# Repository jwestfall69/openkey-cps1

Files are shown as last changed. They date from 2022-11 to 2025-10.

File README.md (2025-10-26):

# openkey-cps1
---
* [Overview](#overview)
* [Project Status](#project-status)
* [Supported C Boards](#supported-c-boards)
* [CPS 1 Case](#cps-1-case)
* [Supported Games / B-XX Chips](#supported-games--b-xx-chips)
  * [CPS 1](#cps-1)
  * [CPS 1.5](#cps-15)
  * [B-XX](#b-xx)
* [Hardware](#hardware)
  * [PCB Manufacturing](#pcb-manufacturing)
  * [BOM](#bom)
  * [Assembly](#assembly)
    * [CPS 1](#cps-1-1)
    * [CPS 1.5](#cps-15-1)
* [Programming](#programming)
  * [Hardware](#hardware-1)
  * [Software](#software)
* [Installation](#installation)
  * [CPS 1](#cps-1-2)
  * [CPS 1.5](#cps-15-2)
  * [Reset Header (optional)](#reset-header-optional)
    * [Reset Capacitor Locations](#reset-capacitor-locations)
    * [Reset Signal Locations](#reset-signal-locations)
    * [Reset Cable](#reset-cable)
    * [Reset Delay Jumper](#reset-delay-jumper)
* [Reverting a modified C Board](#reverting-a-modified-c-board)

## Overview
This is an open source/hardware implementation of an on the fly CPS B-21 chip programmer that consists of a PCB that sits between CPS1/1.5 B and C boards.

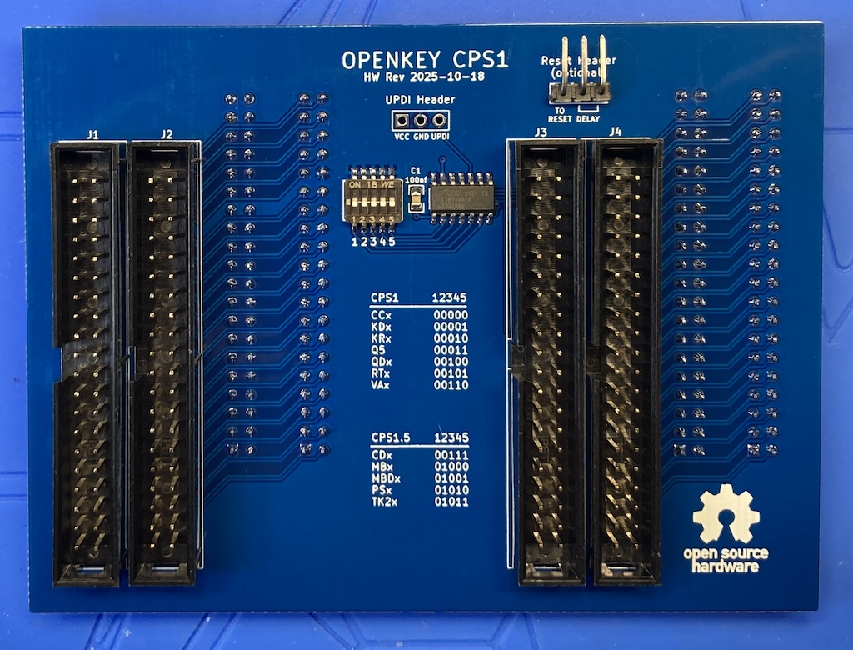
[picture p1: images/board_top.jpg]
board pics
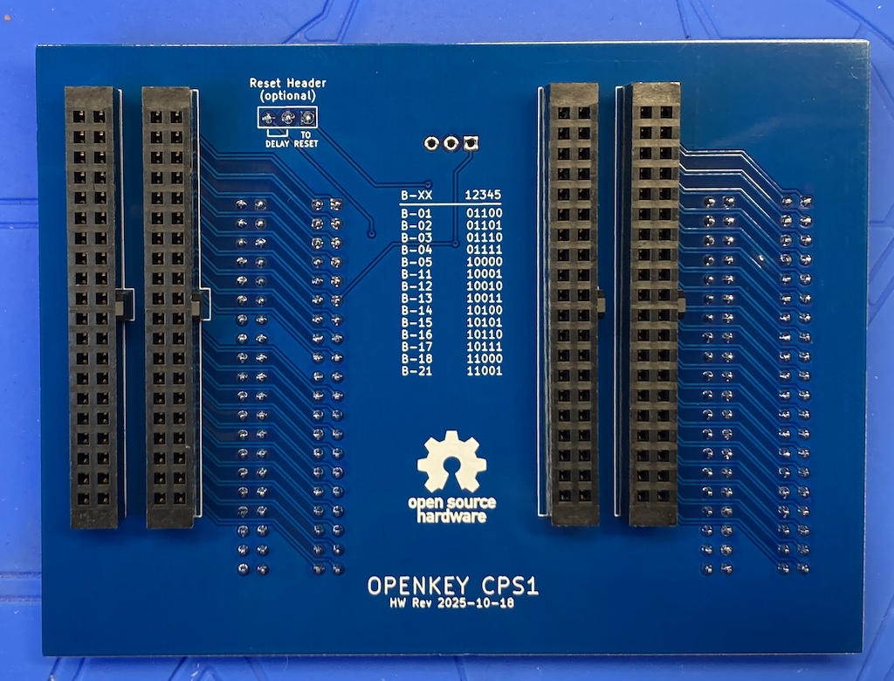
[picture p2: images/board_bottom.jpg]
board pics
 

Installed:<br>
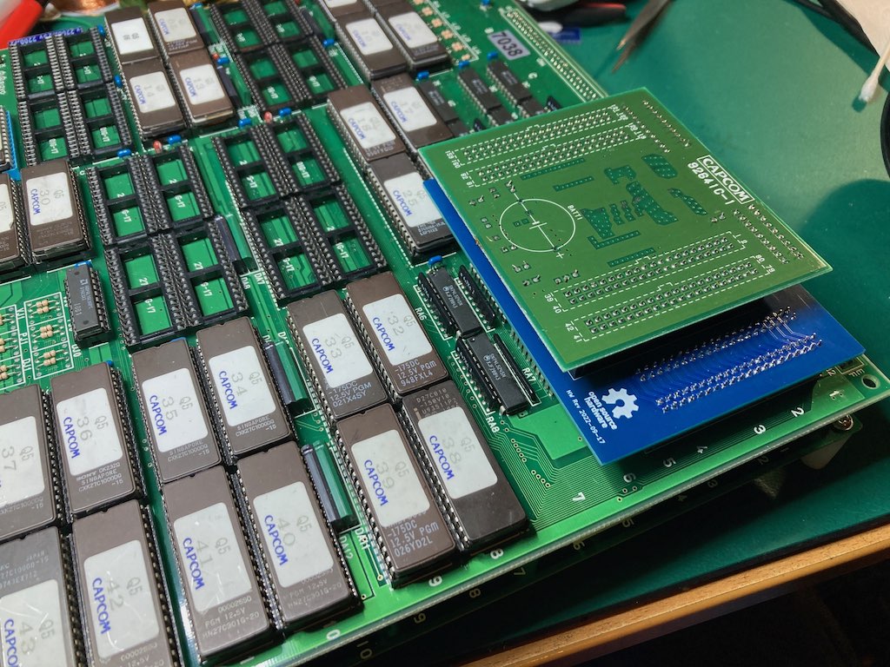
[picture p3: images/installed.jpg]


This project is providing the same functionality as [Undamned's InfiniKey-CPS1](https://www.arcade-projects.com/threads/infinikey-cps1.8337/).  The lack of supply is what prompted me to make openkey-cps1.  If they ever end up coming back in stock please consider purchasing those to support [Undamned](https://www.arcade-projects.com/forums/temple-of-the-undamned.77/)'s work.

Details on *how* to program the CPS B-21 chip configuration can be found in [Eduardo Cruz](http://arcadehacker.blogspot.com/)'s [write up](http://arcadehacker.blogspot.com/2015/04/capcom-cps1-part-1.html) and [youtube video](https://www.youtube.com/watch?v=IBZc__9sM28).  Additional information is also comes from [cps2-reverse](https://gitlab.com/loic.petit/cps2-reverse) project which has details on the [CPS B-21](https://gitlab.com/loic.petit/cps2-reverse/-/tree/master/DLs/DL-0921) chip.

Details on *what* to program can be found in MAME's code for the [CPS1](https://github.com/mamedev/mame/blob/master/src/mame/capcom/cps1_v.cpp#L470).

## Project Status
**PCB:** Done

**Firmware:** Need to get untested games tested

**Documentation:** Done

## Supported C Boards
The following unmodified C Boards are supported

* [90630C-4](https://www.mvs-scans.com/index.php/CPS1_-_C_Board_90630C-4)
* [90631C-5](https://www.mvs-scans.com/index.php/CPS1_-_C_Board_90631C-5)
* [92641C-1](https://www.mvs-scans.com/index.php/CPS1_-_C_Board_92641C-1)

## CPS 1 Case
openkey-cps1 will not fit in the CPS 1 case.  As far as I know only Varith and Capcom World 2 came in a case.  You can still use openkey-cps1 to desuicide the C board.  Replace the battery then boot up the game with openkey-cps1 installed.  Verify it runs as expected, then power off, remove openkey-cps1 and reinstall the board in the case.

## Supported Games / B-XX Chips
openkey-cps1 supports either having a 5 position switch or using solder jumpers for picking what to program into the B-21 Chip.  For the switch, ensure the switches are fully set.  You should hear a click sound as you change the position.

 Below is a list of supported configurations/games and what switches/jumpers must be used for each.

### CPS 1
| Switch<br>12345 | Program ROM Labels | Game Name | Tested / Working |
|:---:|:---:|---|:---:|
| 00000 | CCE<br>CCJ<br>CCU<br> | Captain Commando | YES |
| 00001 | KDE<br>KDJ<br>KDU | The King of Dragons | |
| 00010 | KR_23E<br>KR_23J<br>KR_23U | Knights of the Round | YES |
| 00011 | Q5 | Capcom World 2 | YES |
| 00100 | QDU | Quiz & Dragons | YES |
| 00101 | RTE<br>RTJ<br>RTU | Three Wonders | YES |
| 00110 | VAE<br>VAJ<br>VAU | Varth | YES |

### CPS 1.5
| Switch<br>12345 | Program ROM Labels | Game Name | Tested / Working |
|:---:|:---:|---|:---:|
| 00111 | CDE<br>CDJ<br>CDT<br>CDU | Cadillacs & Dinosaurs | YES |
| 01000 | MBE<br>MBJ<br>MBU | Slam Masters / Muscle Bomber | YES |
| 01001 | MBDE<br>MBDJ | Muscle Bomber Duo | |
| 01010 | PSE<br>PSH<br>PSJ<br>PSU | Punisher | YES |
| 01011 | TK2E<br>TK2J<br>TK2U | Warriors of Fate | |

### B-XX
For B-XX chips prior to B-21 the configurations were hard coded into the chip.  Its possible to program the B-21 to mimic these older chips.

Some older B-XX boards will have the number stamped on instead of etched into the chip.  These stamped numbers maybe incorrect.  For example I have a final fight board that has 04 stamped on as the XX number.  Picking B-04 on openkey-cps1 didn't work.  After dumping the program roms I was able to determine it was the ffightua romset.   [Mame](https://github.com/mamedev/mame/blob/master/src/mame/capcom/cps1_v.cpp#L1754) shows this romset actually uses B-01.  Switching to B-01 made the game work.

| Switch<br>12345 |  B-XX  | Tested / Working |
|:---:|:---:|:---:|
| 01100 | B-01 | YES |
| 01101 | B-02 | |
| 01110 | B-03 | |
| 01111 | B-04 | YES |
| 10000 | B-05 | |
| 10001 | B-11 | YES |
| 10010 | B-12 | YES |
| 10011 | B-13 | YES |
| 10100 | B-14 | YES |
| 10101 | B-15 | |
| 10110 | B-16 | YES |
| 10111 | B-17 | YES |
| 11000 | B-18 | |
| 11001 | B-21 | YES |

## Hardware
### PCB Manufacturing
There are no special requirements for manufacturing.

I've been using [jlcpcb](https://jlcpcb.com/) for PCB manufacturing.  Just watch out that by default they will add an order number to the silk screen unless you tell them not to.

### BOM
| Quantity | Description | Part Number | DigiKey | Mouser | Notes |
|:---:|---|---|---|---|---|
| 1 | ATtiny404 20Mhz | ATTINY404-SSN | [ATTINY404-SSN-ND](https://www.digikey.com/en/products/detail/microchip-technology/ATTINY404-SSN/9947546) | [556-ATTINY404-SSNR](https://www.mouser.com/ProductDetail/Microchip-Technology-Atmel/ATTINY404-SSNR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) | Other ATtiny tinyAVR 0/1/2-series models should be viable as well.  The code compiles to just under 1.5K in size, so any that have 2k or more of flash should work.  Just note I have only tested with 404s |
| 1 | 100nf / 0.1uf SMD Ceramic Capacitor 0805 Size | | | | |
| 1 | 5 Position Slide Switch | Würth Elektronik 416131160805 | [732-3855-2-ND](https://www.digikey.com/en/products/detail/w%C3%BCrth-elektronik/416131160805/3174531) | [710-416131160805](https://www.mouser.com/ProductDetail/Wurth-Elektronik/416131160805?qs=2kOmHSv6VfT1rqUsojuQog%3D%3D) | **Optional** not needed if using the solder jumpers to pick the game.
| 4 | CPS1: 2x20 Pin Male IDC connector<br>CPS1.5: 2x20pin Male Header (no shroud) | SBH11-PBPC-D20-ST-BK<br>N/A | [S9175-ND](https://www.digikey.com/en/products/detail/sullins-connector-solutions/SBH11-PBPC-D20-ST-BK/1990068)<br>[2x20 Pin Header](https://www.amazon.com/dp/B083DYVWDN?psc=1&ref=ppx_yo2ov_dt_b_product_details) | ?? | This is just a standard IDE male connector<br>This is just a normal 2x20 Pin header you might find for a PI's GPIO pins |
| 4 | 2x20 Pin Female socket | SFH11-PBPC-D20-ST-BK | [S9200-ND](https://www.digikey.com/en/products/detail/sullins-connector-solutions/SFH11-PBPC-D20-ST-BK/1990093) | ?? |  |

**IMPORTANT** For the 2x20 Pin Female socket, if you choose a different part, make sure you get ones that have the extra plastic on the edge as seen below.

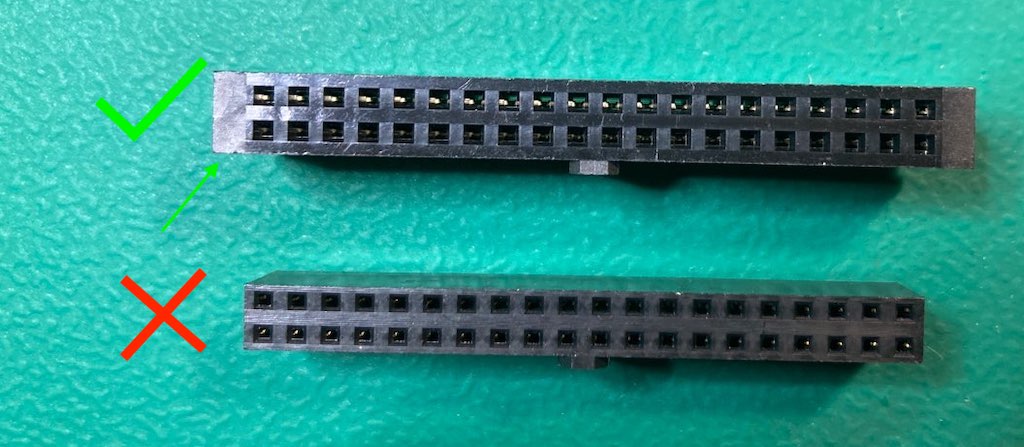
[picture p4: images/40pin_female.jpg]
40 pin female


The extra plastic prevents the connector from being inserted off-by-one.  An off-by-one insertion will cause a direct short to ground. This can cause catastrophic damage to your Game PCB if your power supply doesn't have short circuit protection.

Don't be fooled into thinking you don't need the extra plastic because you see the key. The bottom connector for example is too skinny for the key to actually prevent off-by-one insertion.  Ask me how I know ;)

### Assembly
#### CPS 1
Nothing special is needed when assembling a openkey-cps1 that will be used in a normal non-case'd CPS1 board.  Install SMD components first, then install the 40 pin male/female connectors.

#### CPS 1.5
Installing openkey-cps1 in a CPS 1.5 case is a tight fit height wise.  The pins that stick out of the C board are at the point of touching the top of the case.  If you are ok with this just use the 40 pin IDE style connectors.  Otherwise you can do the following.

To deal with this the best course of action is to only have raw pins for the male 40 pin connectors instead of ones with the plastic shroud.  This will allow the C board to sit flush with the openkey-cps1 board and reduce the height enough to not touch the top of the case.  Below is what has worked well for me, but there maybe better ways.

Some things to consider:
  * The normal pin length of a male pin is 6mm
  * The max pin height above the openkey-cps1 board should **not exceed 7mm**.  Any longer and the pin will bottom out on the female connector on the C Board.  This will cause the C board to not sit flush to the openkey-cps1 board and defeat the purpose of using raw pins.
  * You can't just install the normal 40pin IDE style connector then remove the shroud.  The resulting pin length ends up being 8mm.
  * You can't just install a normal 40 pin header and remove the plastic.  The resulting pin length ends up being 8mm.
  * The total length of metal pin on most headers is going to be 11.5mm
  * PCB thickness should be 1.6mm, which leave about 10mm worth of metal pin length we must deal with.

This method targets having 7mm above and 3mm below the openkey-cps1 board.  I've tried 6mm/4mm, but that 4mm is long enough there is risk it could hit/damage components on the B board.

You will want 4 normal 2x20 pin headers where the total metal length is 11.5mm.  Additionally you will want something you can use as a 1.5mm spacer.  I'm using the 2 black 24AWG wires in the picture below.

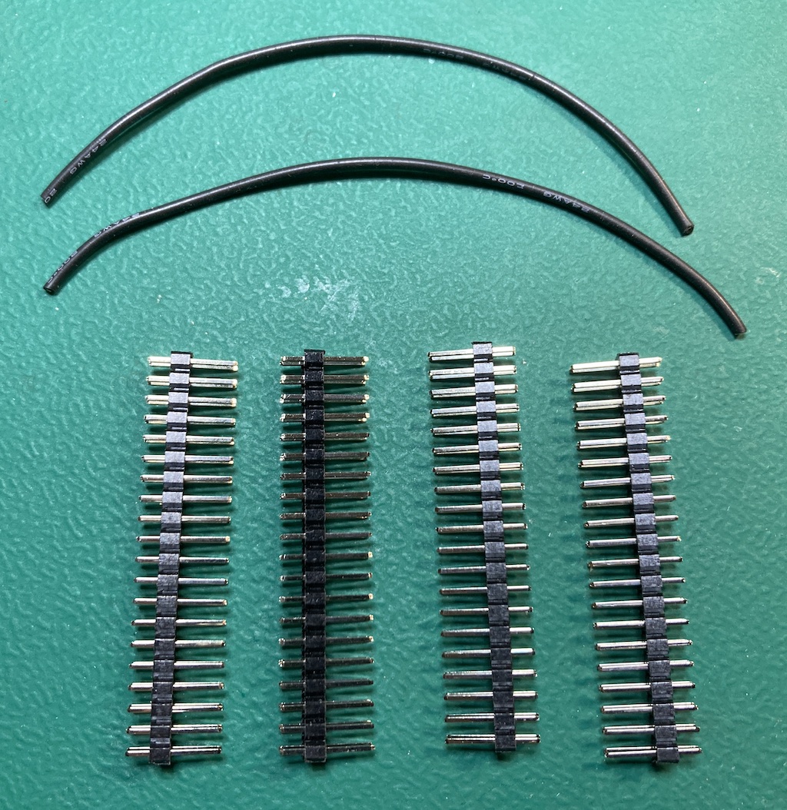
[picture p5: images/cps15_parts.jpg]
cps15 parts


You will want to install 2 of the 2x20 pin header upside into board.  I would advise doing the 2 outer ones first. Put the 1.5mm spacer between the board and the plastic part of the connector as seen below.

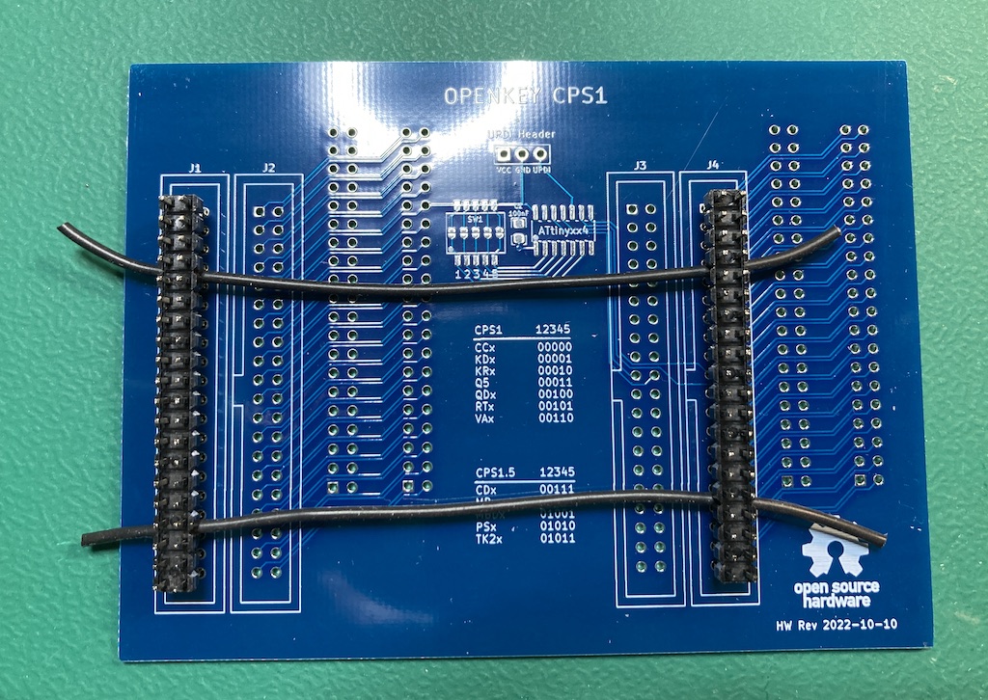
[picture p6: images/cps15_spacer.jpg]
cps15 spacer


Now flip the board over to the side we will be soldering.  It should look something like this.  

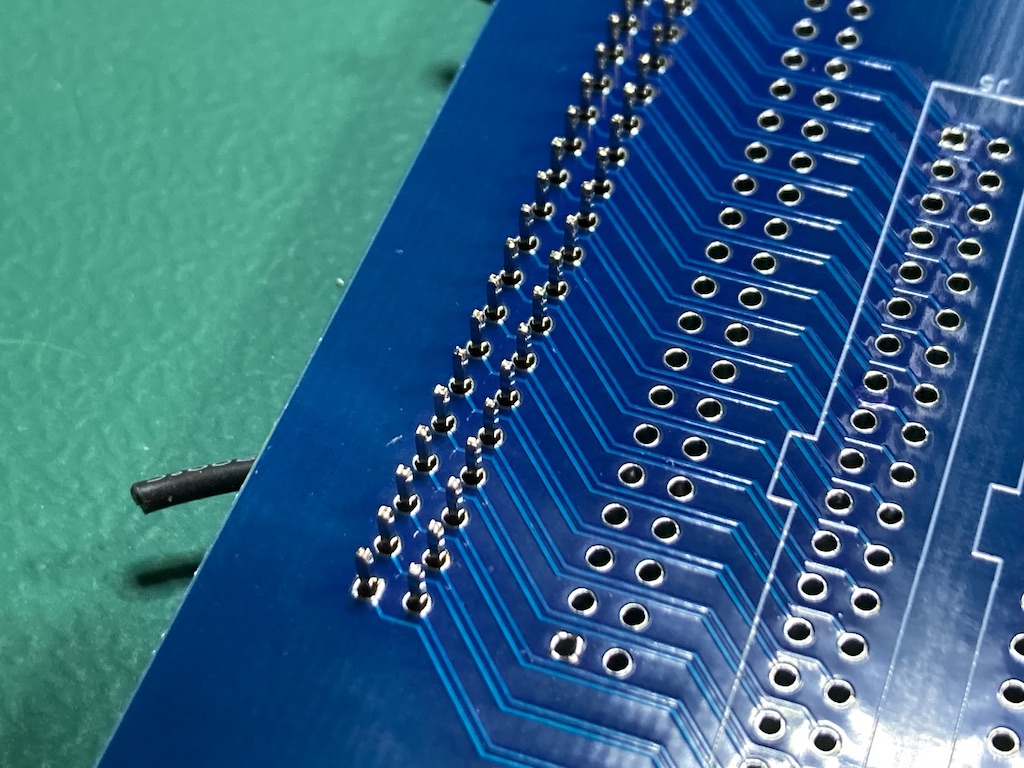
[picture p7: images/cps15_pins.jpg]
cps15 pins


The length of the pins should be 3mm, which will mean 7mm on the top.

At this point I would tack 2 pins on each connector then verify spacing of the connectors looks good.  It should look something like this (with the spacer wires removed)

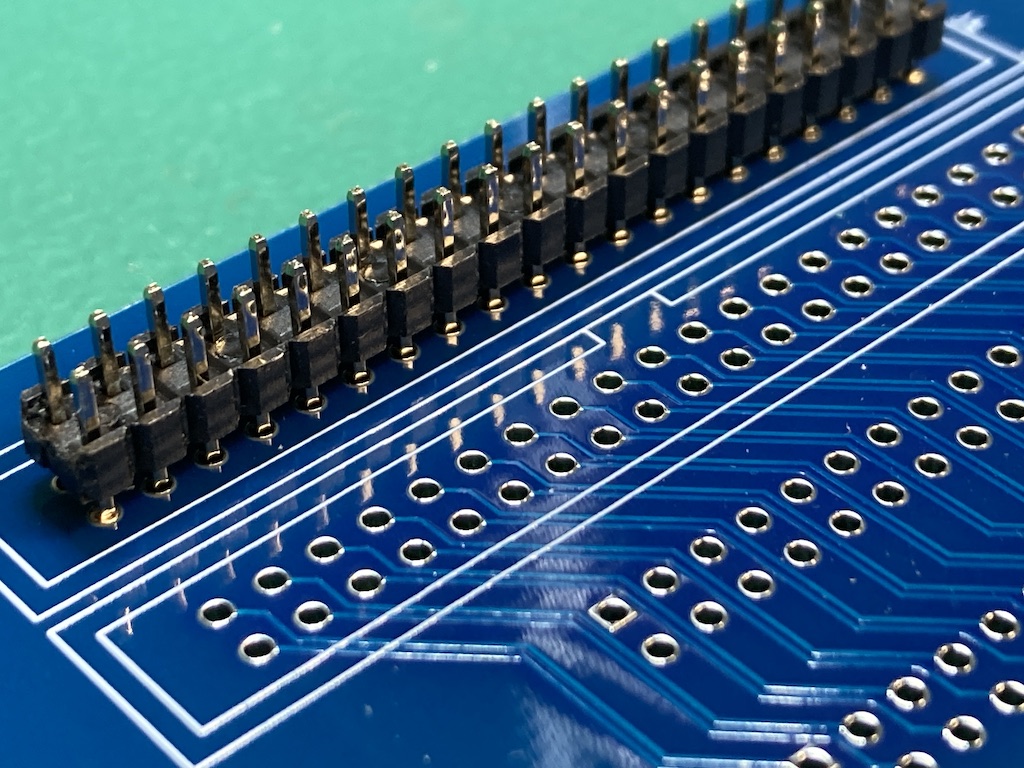
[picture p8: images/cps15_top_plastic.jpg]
cps15 top plastic


If you measure the pin lengths they should be right at 7mm.

Fully solder those 2 connectors.  Its extra importing you check your soldering that this point.  The next steps will involve removing the plastic part of the connectors which will make every pin independent and a pita to solder.

To protect the board I would put down some painters tape.  Additionally I use this [chip lifter](https://www.amazon.com/Wiha-27921-PicoFinish-Precision-Chiplifter/dp/B0875LSTD3/ref=sr_1_5)  as my pry tool. The grove makes it possible to get in between the pins to when prying up the plastic.

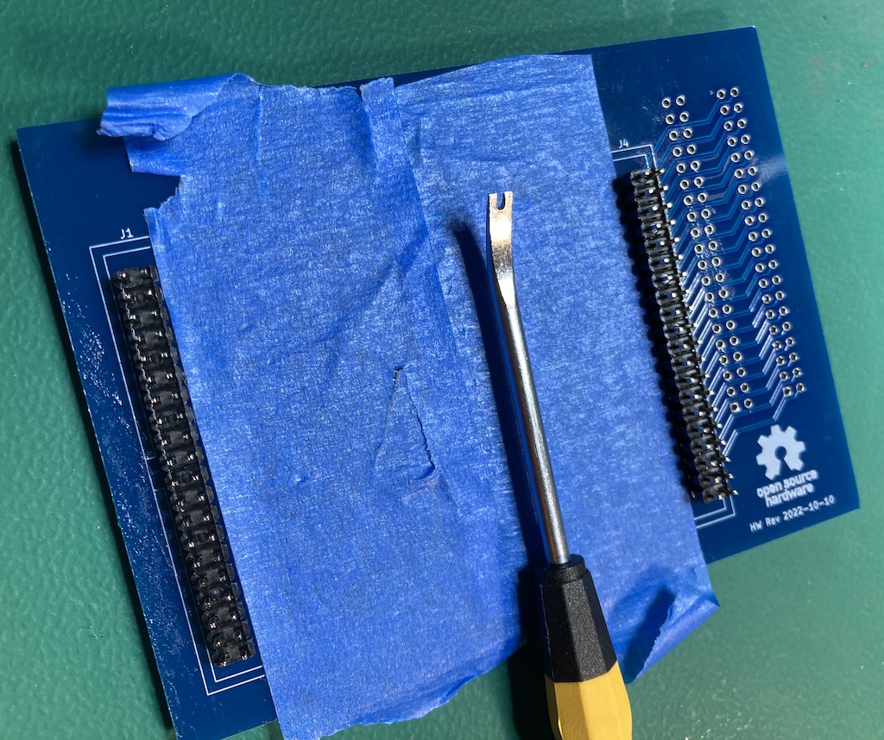
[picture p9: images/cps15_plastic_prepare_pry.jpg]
cps15 plastic prepare pry


If you have a hot air station you can use it to heat (200C) up the plastic to make it easier to get off.  You will want to do the removable in a couple passes with your pry tool, lifting up the plastic a few mm per pass.

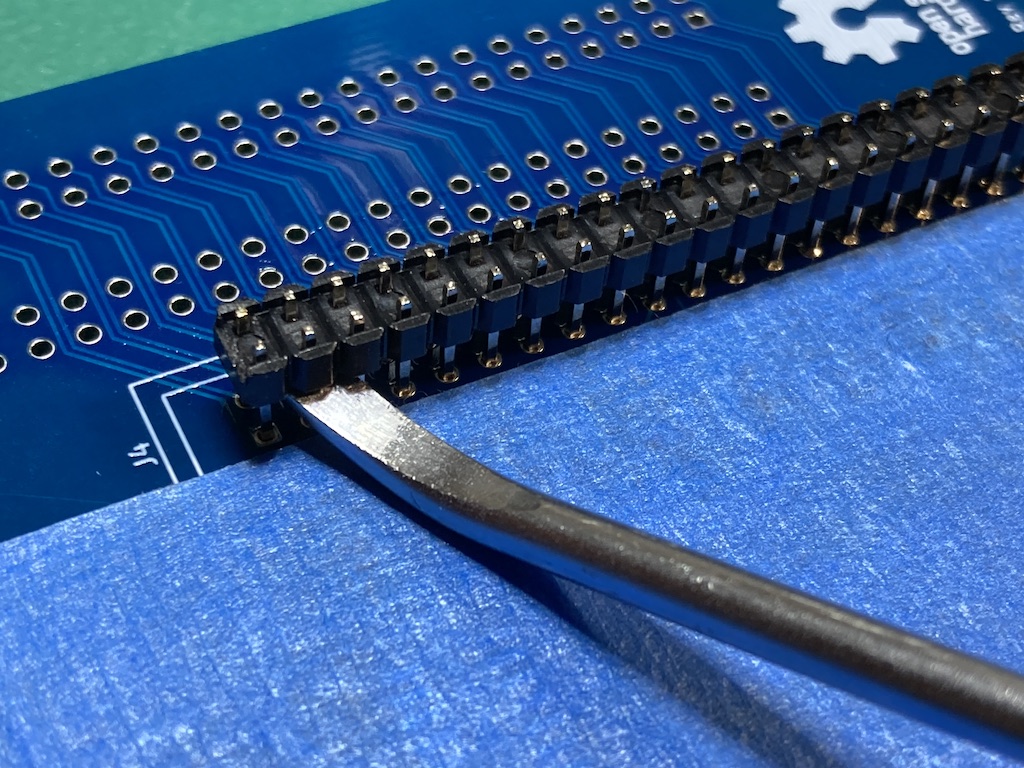
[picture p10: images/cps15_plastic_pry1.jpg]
cps15 plastic pry 1


As you get the plastic higher up on the pins it can be helpful to add a spacer under you pry tool.  I'm just using a old prototype board.

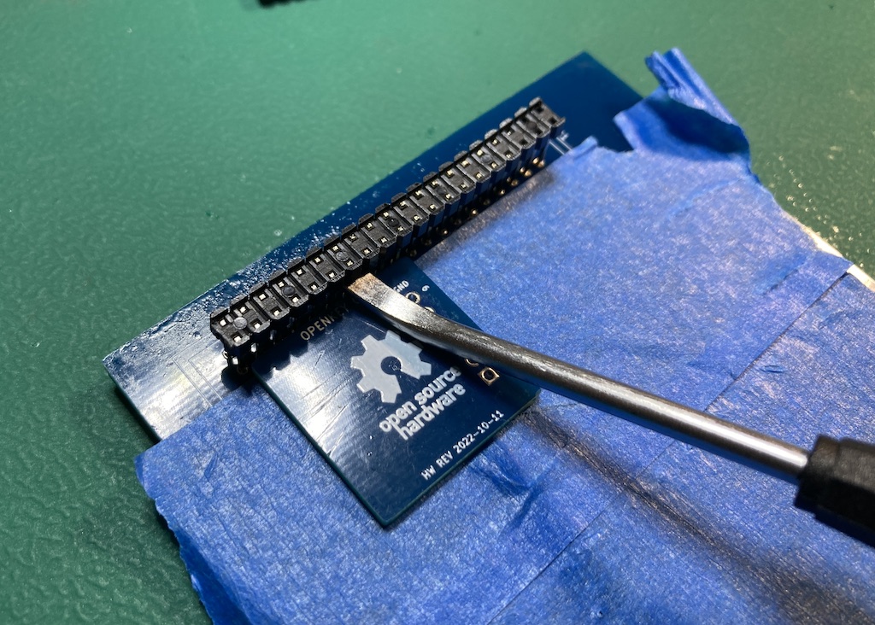
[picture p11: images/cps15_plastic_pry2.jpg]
cps15 plastic pry 2


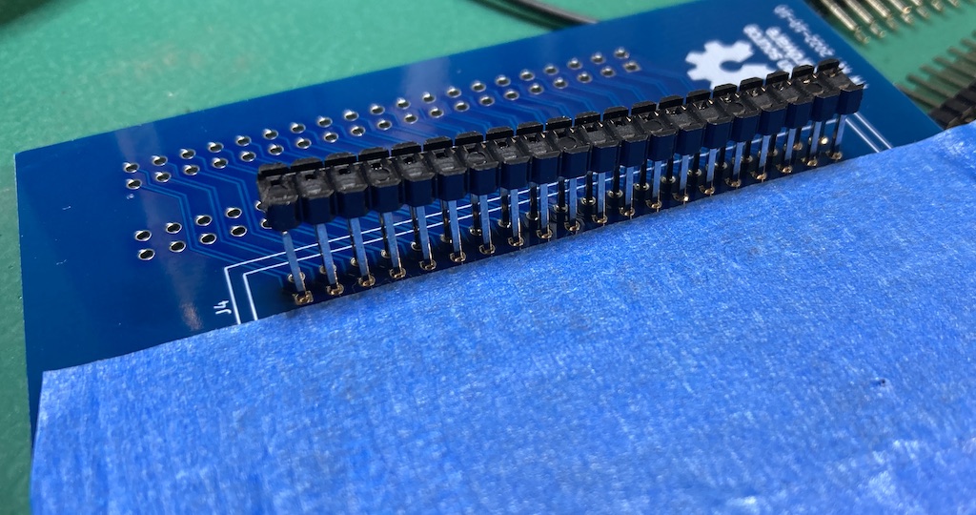
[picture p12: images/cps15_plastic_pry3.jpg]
cps15 plastic pry 3


Once you get both plastics off it should looks like this

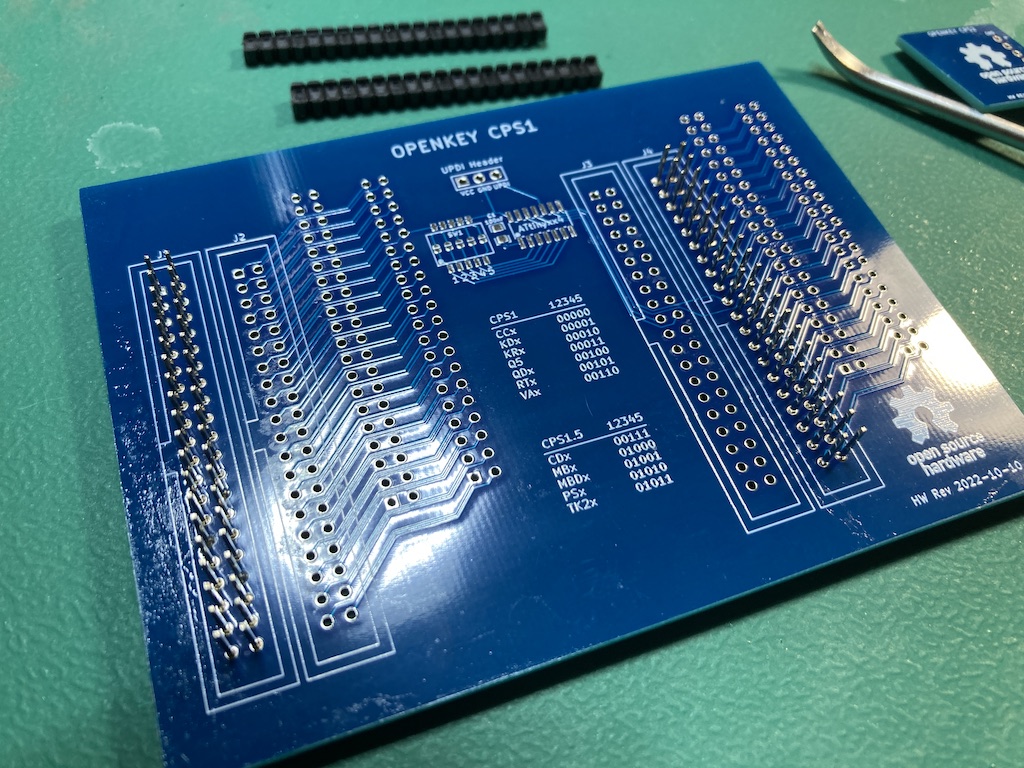
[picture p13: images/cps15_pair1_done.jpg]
cps15 pair1 done


Then you can go onto the middle 2 connectors.  You can bypass using the 1.5mm spacer on these.  Instead just put the connects in the PCB upside down as before, then flip PCB over as if you were going to solder them.  The already soldered connectors will hold the PCB 7mm off your table, which will mean your to be installed connectors will also be 7mm off your table.  Tack, verify and then fully solder.

Repeat the process to remove the plastic

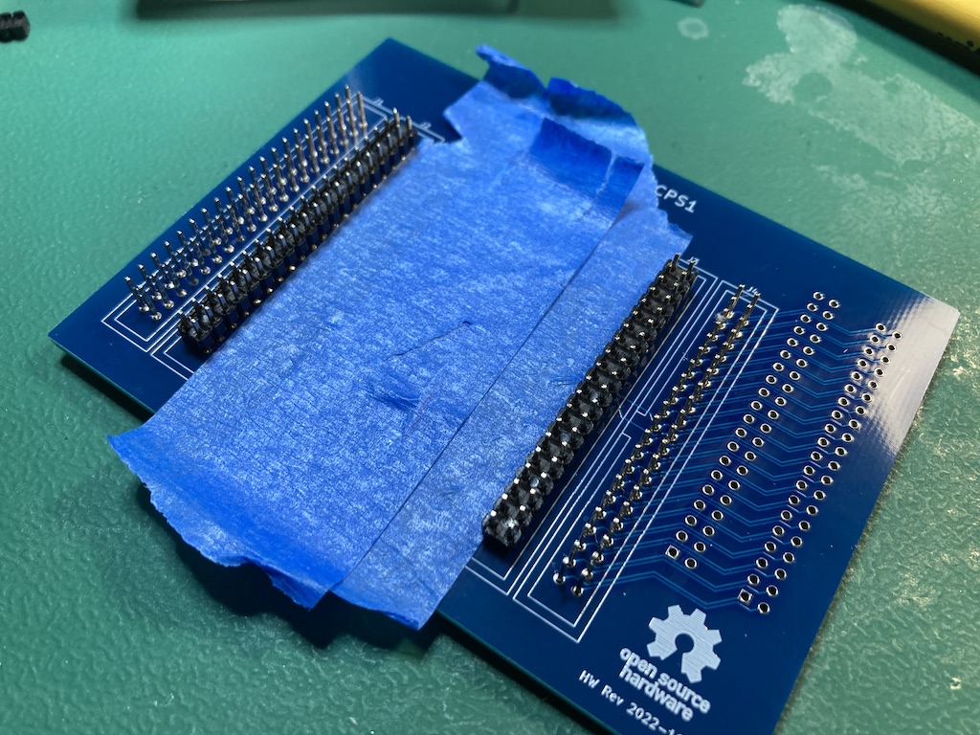
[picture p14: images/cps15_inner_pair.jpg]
cps15 inner pair


When you are all done you should have this

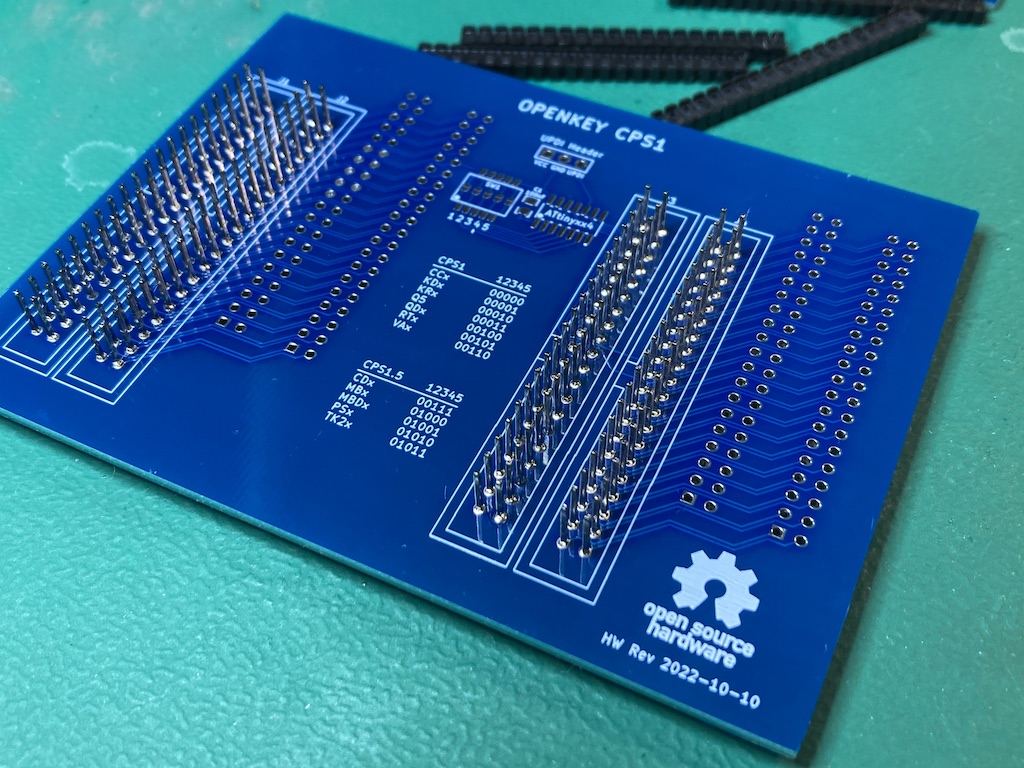
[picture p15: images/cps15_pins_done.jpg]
cps15 pins done


Now do a test fit of the C board and it should be flush with the openkey-cps1 PCB

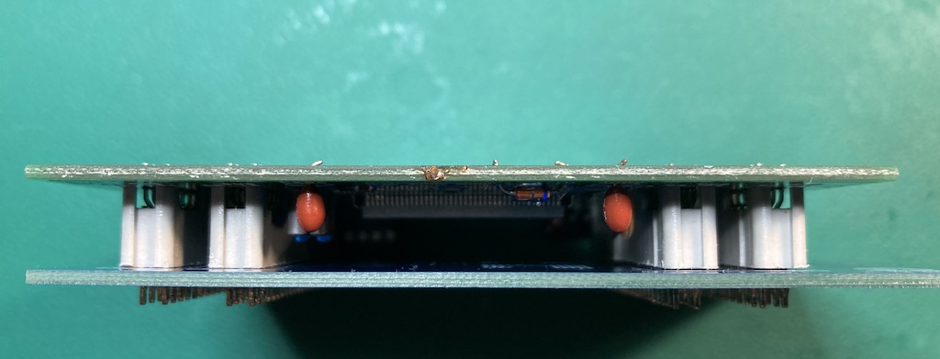
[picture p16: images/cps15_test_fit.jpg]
cps15 test fit


Install the SMD components and female 40 pin connectors.  This one was going on my Punisher board, so I just used the solder jumpers instead of installing the 5 position switch.

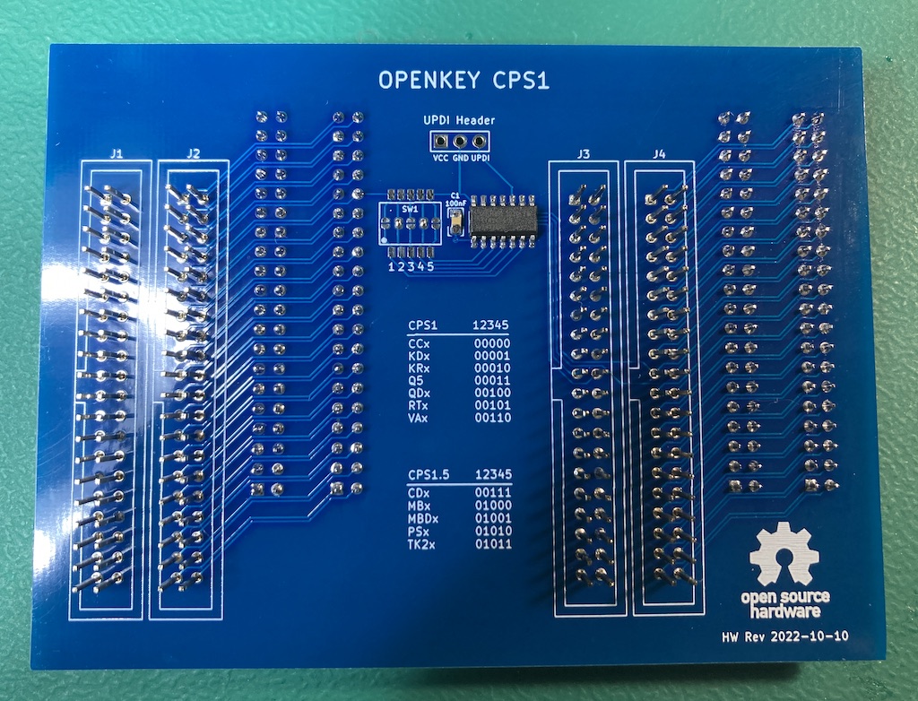
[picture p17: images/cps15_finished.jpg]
cps15 finished


## Programming
The latest firmware will work on both revisions of openkey-cps1 hardware.

### Hardware
Programming is done with a UPDI programmer.  I've been using this one:

[Serial UPDI Programmer for ATmega 0-Series, or ATtiny 0-Series or 1-Series, or AVR DA or AVR DB](https://www.amazon.com/dp/B09X64YRLD?psc=1&ref=ppx_yo2ov_dt_b_product_details)

Note: This programmer (and likely others) has a switch for 3.3V and 5V.  Set it to 5V.

The openkey-cps1 programming port is setup so you can wedge the pins from the above programmer directly into them to programming.

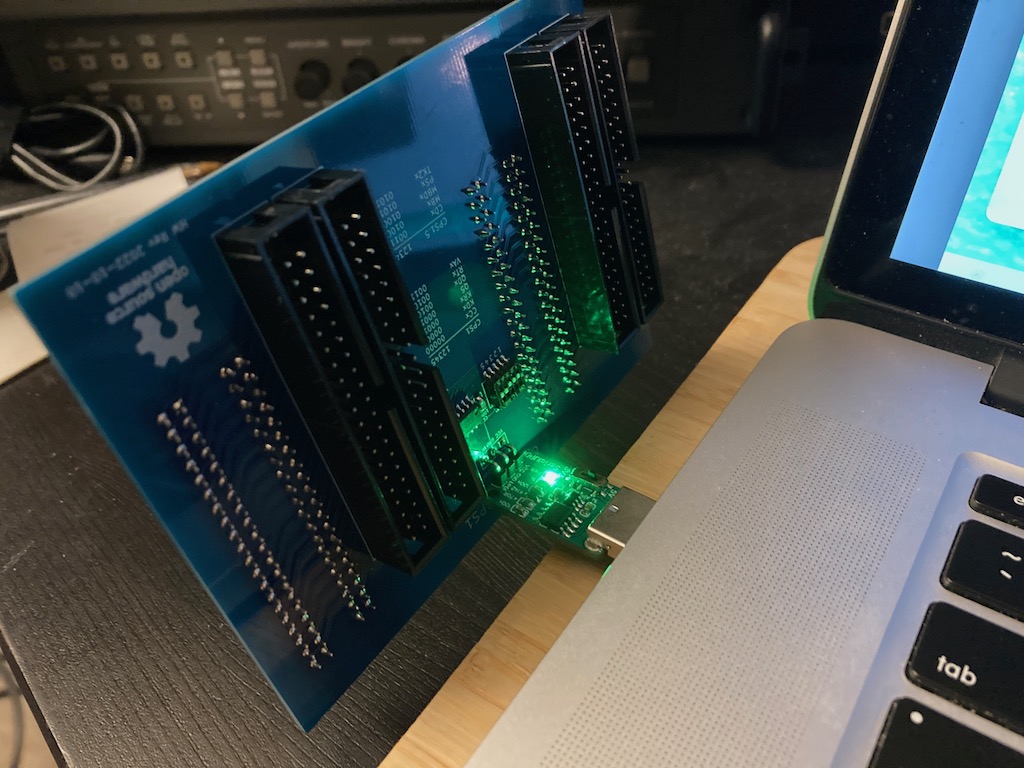
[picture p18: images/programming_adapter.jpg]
programming adapter


Of course be sure you properly orient the board so the labeled pin/holes match up.  vcc to vcc, gnd to gnd, and updi to updi.

### Software
For software I've been using the [Arduino IDE](https://www.arduino.cc/en/software/) with [megaTinyCore](https://github.com/SpenceKonde/megaTinyCore), which adds support for tinyAVR 0/1/2-Series MCUs.

To install the megaTinyCore you, should just need to add http://drazzy.com/package_drazzy.com_index.json to "Additional Boards Manager URLs" in the settings for the Arduino IDE.

From there you need to configure the board/programming settings.  I've been using these:

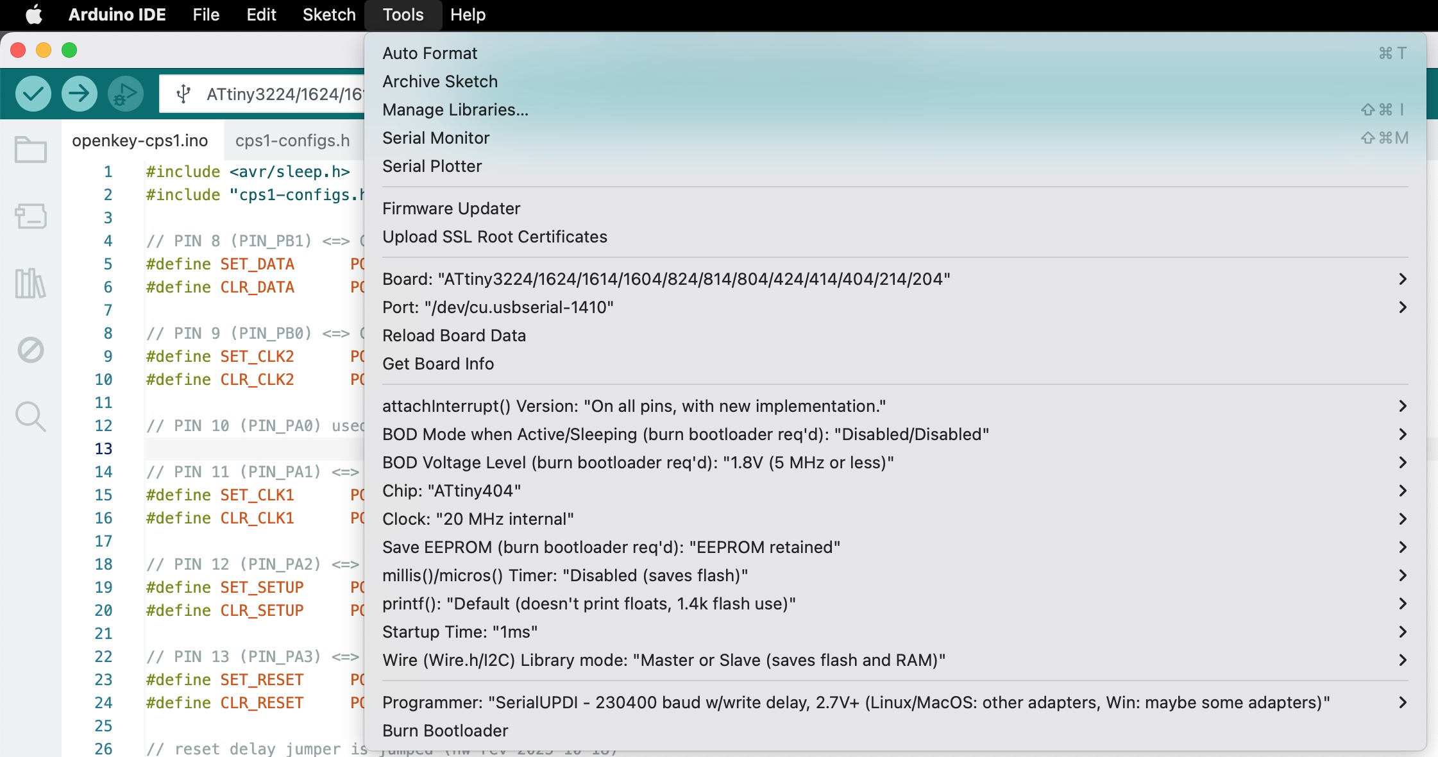
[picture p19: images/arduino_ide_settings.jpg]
arduino ide settings

**NOTE:** The "Startup Time" was adjusted from my previous picture of the settings, from 0ms to 1ms.  In testing I found when using a 0ms startup there is a small chance the ATtiny won't even execute any code.

## Installation
### CPS 1
Nothing really special here.  Use the dip switches or solder jumpers to pick your game/chip and put the openkey-cps1 board between your C and B boards.  The male/female connectors should prevent you from installing incorrectly.

### CPS 1.5
This is assuming you are using an openkey-cps1 board with the raw pin headers on top.  There is nothing preventing you from install the C board incorrectly.

Use the dip switches or solder jumpers to pick your game.

Verify you have the C board oriented the correct way as seen below.

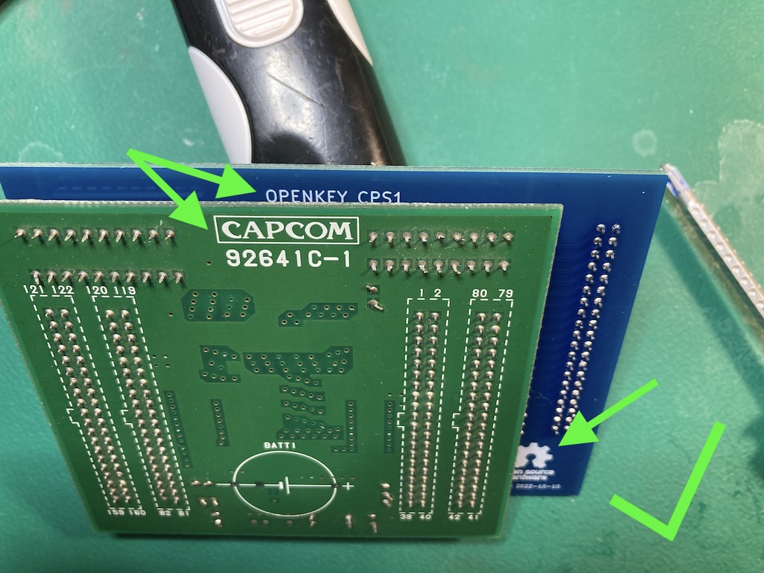
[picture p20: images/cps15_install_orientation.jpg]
cps15 install orientation


The C board female connector will prevent you from installing it to high or low, but it will not prevent installation to the left or the right by one.

Check both sides of the female C board connector to verify you dont see any of the pins.

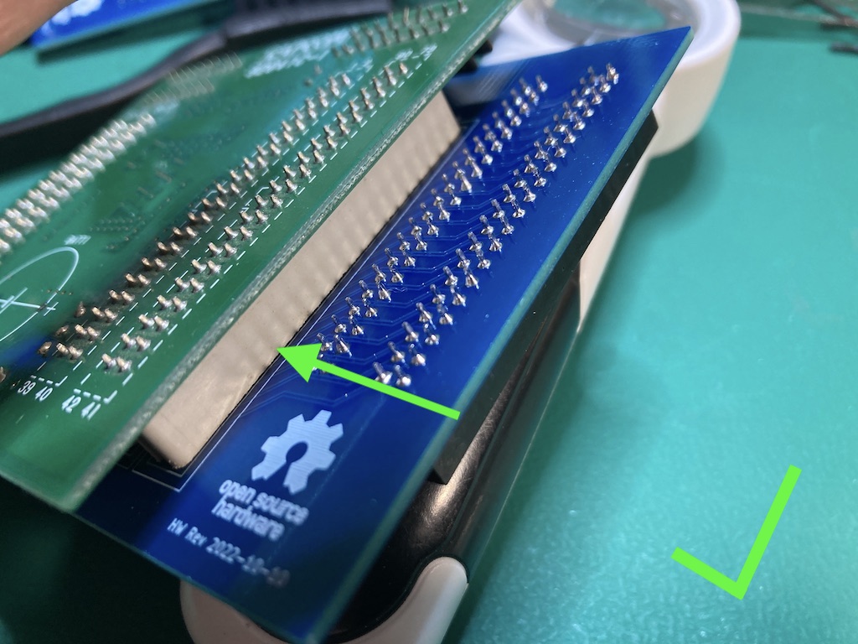
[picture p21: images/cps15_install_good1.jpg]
cps15 install good1


other side
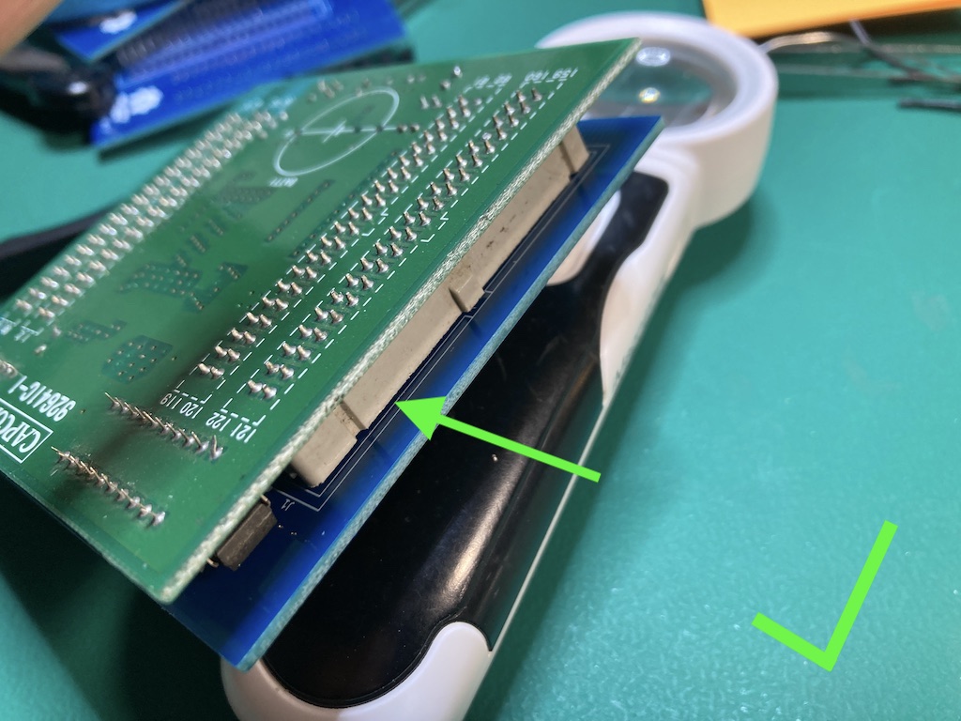
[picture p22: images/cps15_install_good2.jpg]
cps15 install good2


If its off by one of the sides will look like this
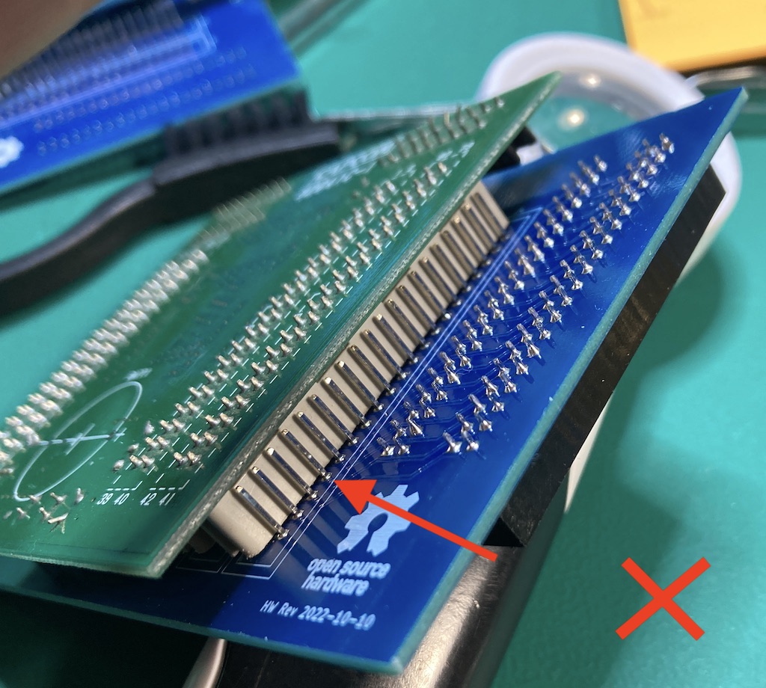
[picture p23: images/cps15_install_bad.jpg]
cps15 install bad


### Reset Header (optional)
In openkey-cps1 hardware revision 2025-10-18 an optional reset header was added to allow hooking up openkey to the reset line of the A board.  Its **unlikley** you would need this and I would avoid using it.

Openkey-cps1 is dependent on being able to re-program on the B-21 chip while the cps1 board is in reset.  This is because 2 of the pins related to programming are part of the data bus used by the main CPU to talk to the B-21 chip.  If openkey-cps1 were to try and do any of its programming outside of reset it would cause a bus conflict with the main CPU also trying to use those 2 pins and programming will fail.

#### Reset Capacitor Locations
The length of time the cps1 board is in reset is highly dependent on the reset capacitor located on the A board.  If this capacitor is faulty or going bad it can greatly reduce the amount of time the board is in reset when power is applied.  Before trying to use the reset header on the openkey-cps1 I would first try replacing the reset capacitor.

**Long A Board:**<br>
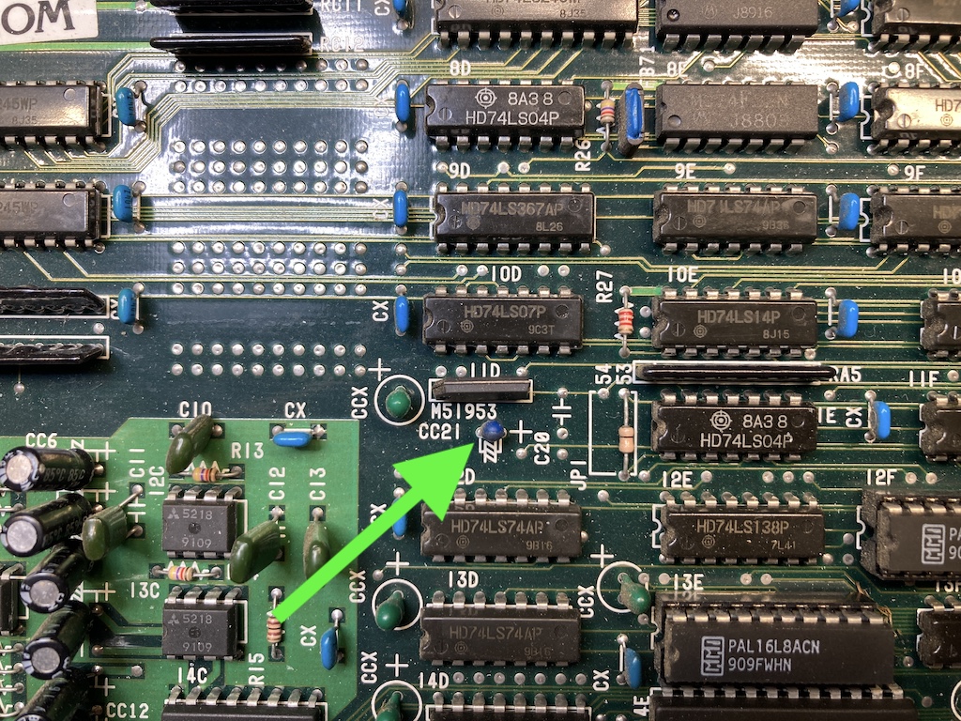
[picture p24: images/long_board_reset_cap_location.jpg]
long board reset cap location


**Short A Board:**<br>
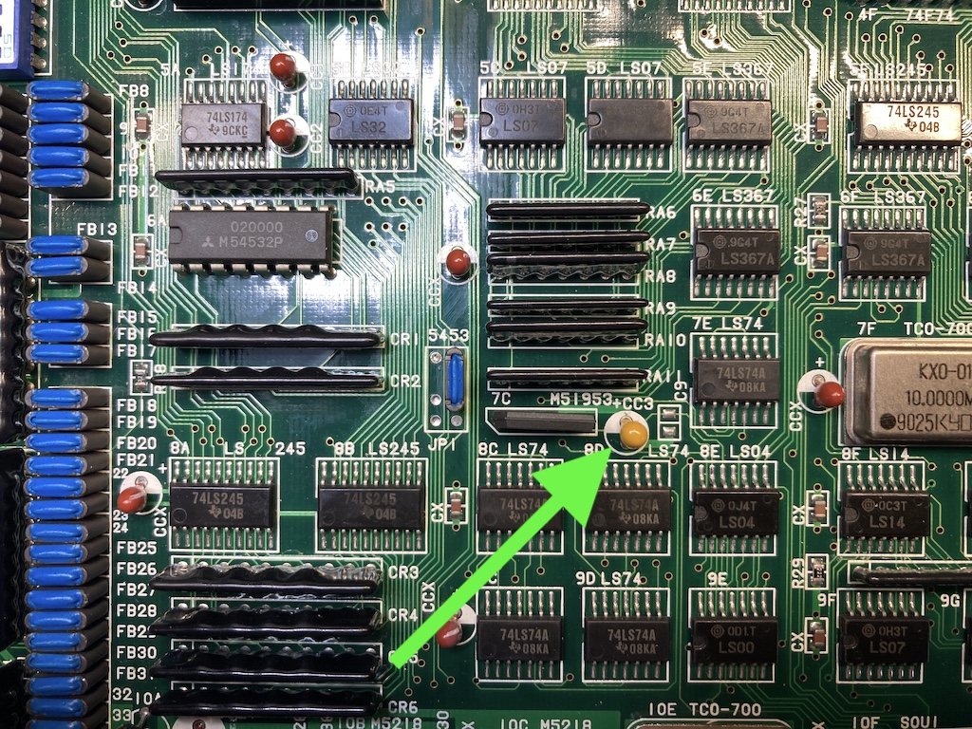
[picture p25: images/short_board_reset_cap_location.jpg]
short board reset cap location


On both boards its a 1uf/16V ceramic capacitor (higher voltages are ok).

#### Reset Signal Locations
The location provided for each A board type is a through hole.  I would advise installing a right angle header instead of directly soldering a wire.  This will make it easy to connect/disconnect the cable both on the A board and openkey-cps1.

**Long A Board:**<br>
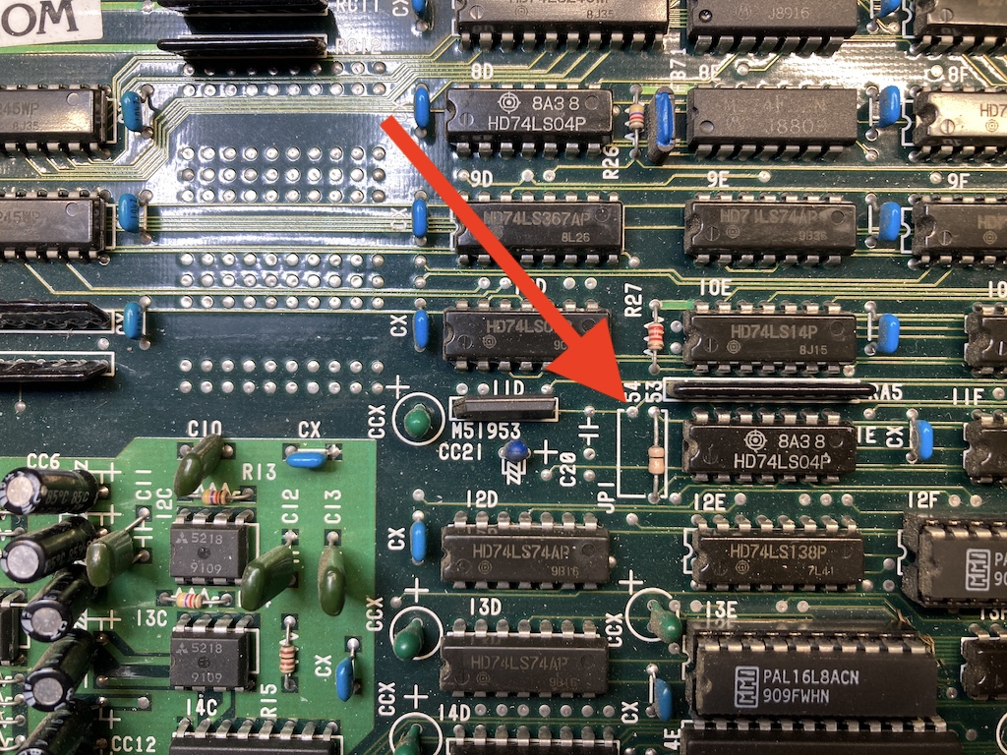
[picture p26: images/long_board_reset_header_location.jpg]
long board reset header location

**Long A Board Installed:**<br>
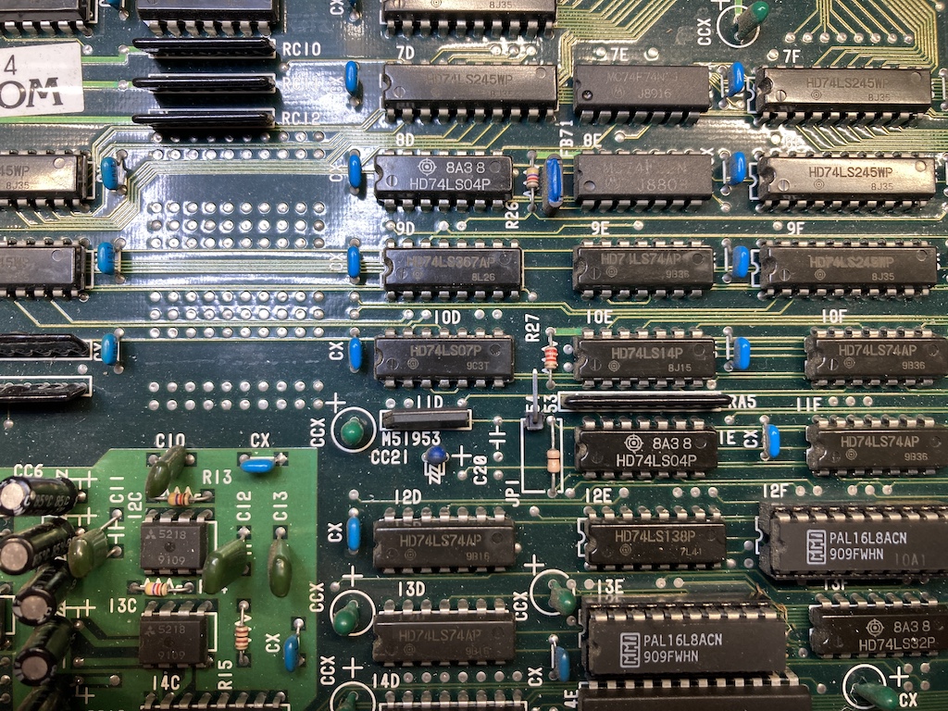
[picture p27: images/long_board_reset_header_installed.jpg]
long board reset header install


**Short A Board:**<br>
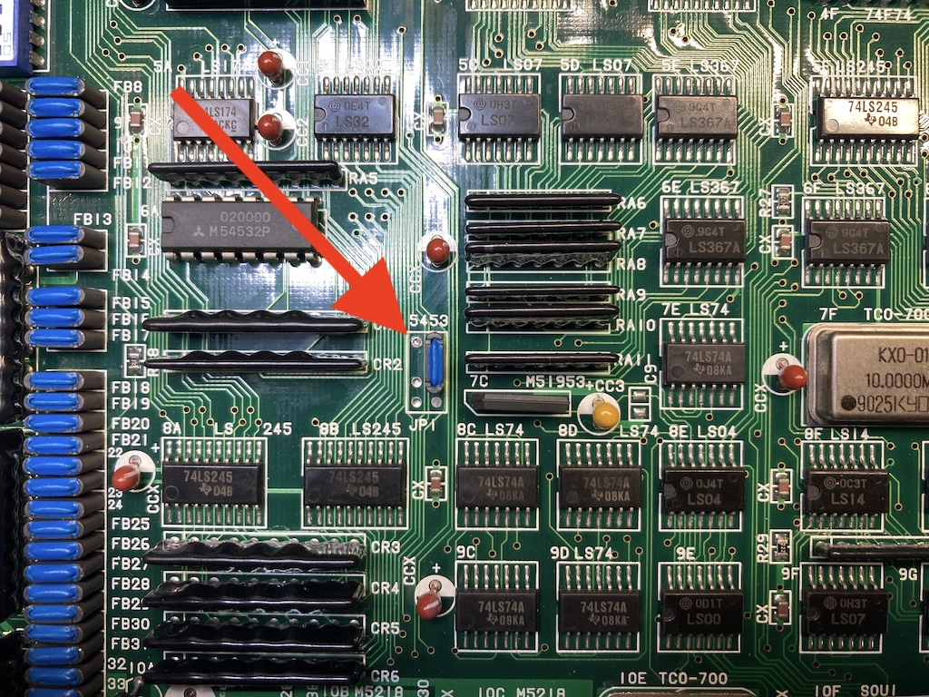
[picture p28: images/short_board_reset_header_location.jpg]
short board reset header location

**Short A Board Installed:**<br>
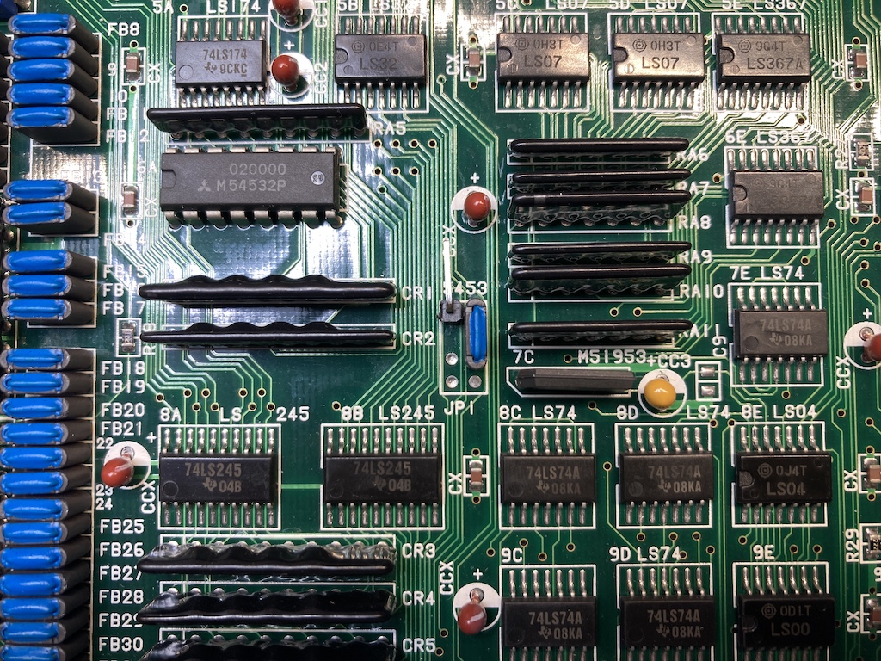
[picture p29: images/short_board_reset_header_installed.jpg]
short board reset header install


#### Reset Cable
Once you've added the reset header on the A board, run a cable from it to pin 1 on the reset header of the openkey-cps1 as shown below.

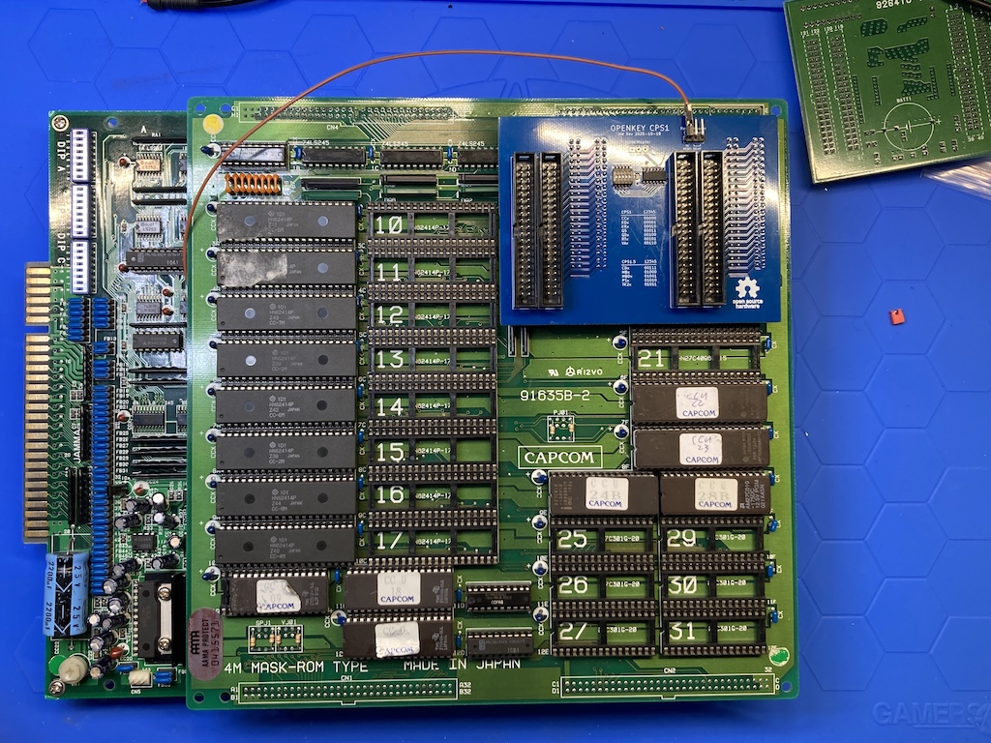
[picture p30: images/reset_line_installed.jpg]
reset line installed


Then install the C board onto openkey-cps1 as you normally would.

#### Reset Delay Jumper
With the reset cable hooked up, openkey-cps1 will hold the cps1 board in reset while its programming, then release when complete.  Pins 2 and 3 of the reset header on openkey-cps1 are a jumper that will cause openkey-cps1 to keep the cps1 board in reset longer.  When jumped the firmware will hold the cps1 board in reset for 1 second before and after programming.

**IMPORTANT**: If this jumper is jumped and the reset cable is not hooked up, programming will fail 100% of the time!

## Reverting a modified C Board
Its pretty common to find one of the required C boards as having been modified to disable using the programmable configuration.  This forces them to use their default configuration.

The tale tale sign of a modified C board are pins 45 and 46 will have cut traces (normally they go to ground) and a wire from them to some point on the C board that is supplying 5 volts.  For example

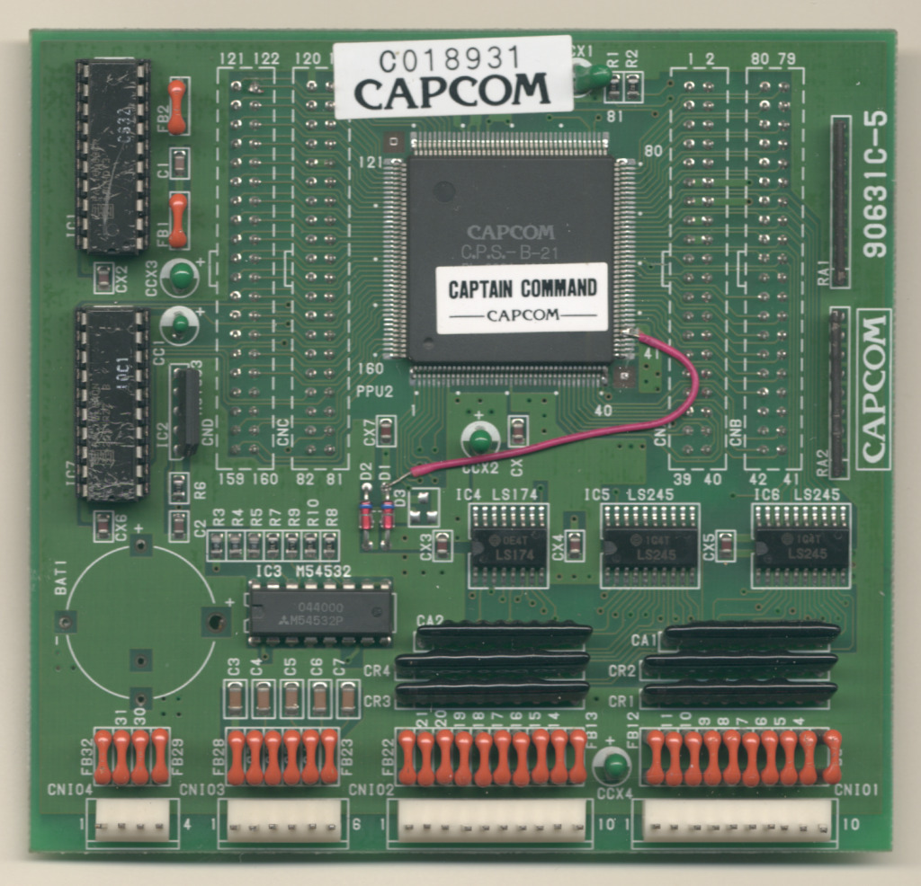
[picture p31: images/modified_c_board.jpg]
modified c board


The way I normally revert them is to remove the wire, and then put a solder blob so that pins 45, 46, and 47 (ground) are bridged together.  This puts the board back in its original state with all 3 of those pins being tied to ground.

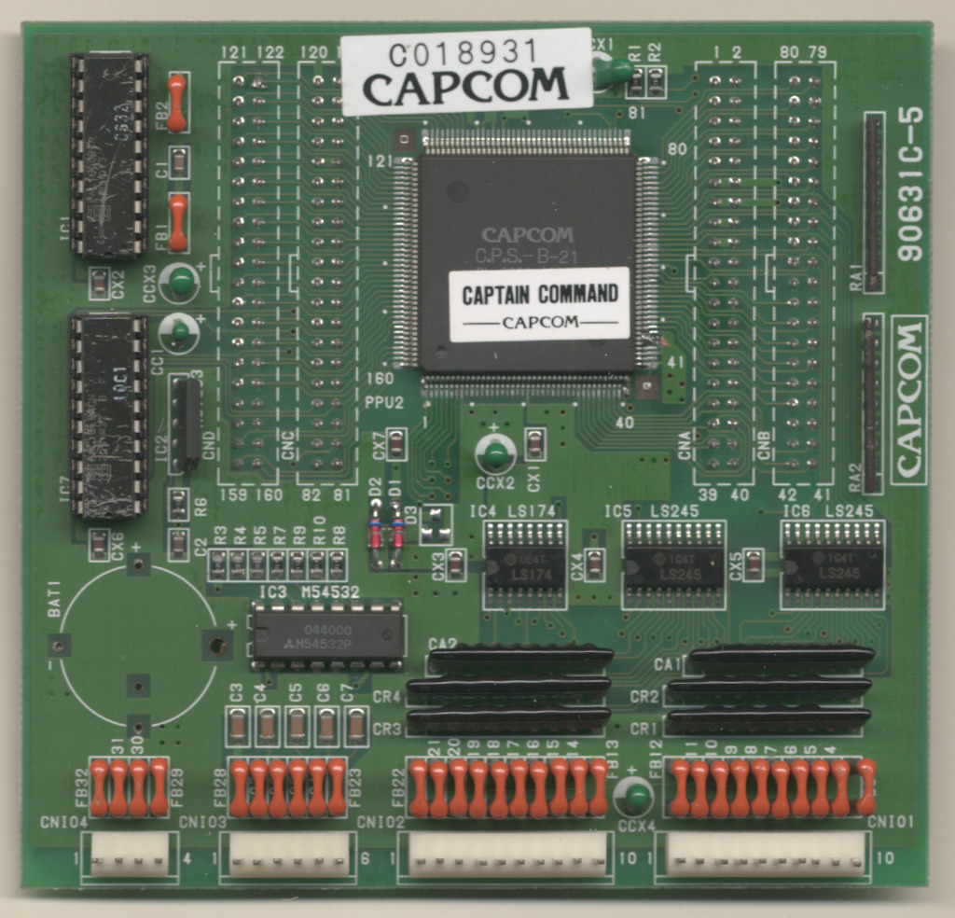
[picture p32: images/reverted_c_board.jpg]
reverted_c_board


Here is a close up of the solder blob on the pins

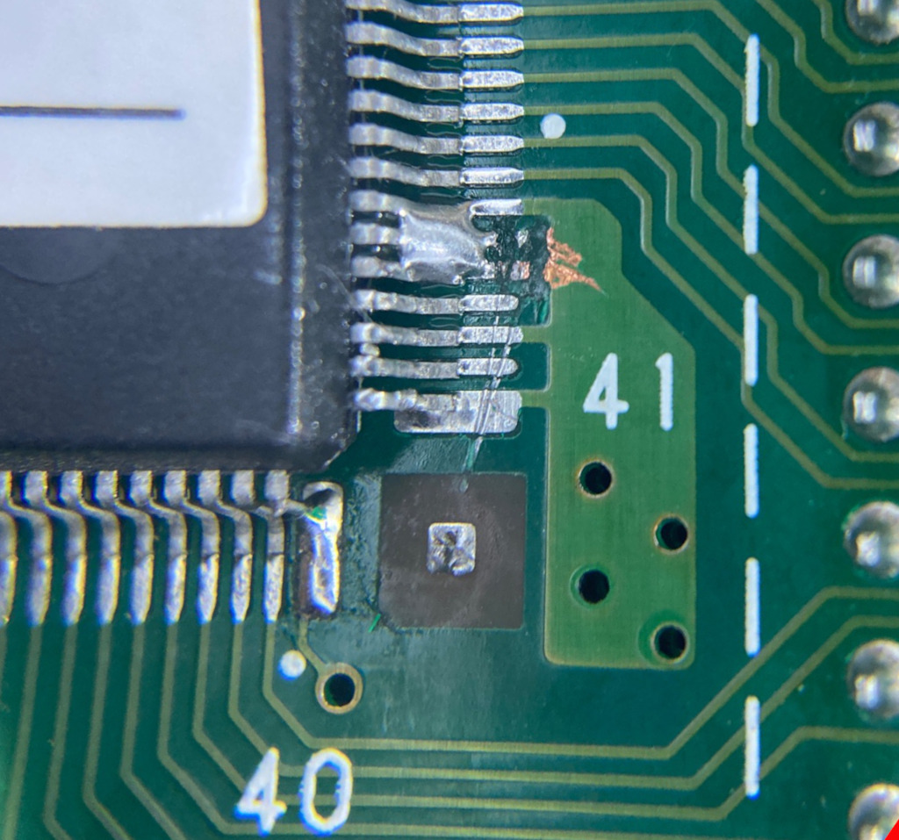
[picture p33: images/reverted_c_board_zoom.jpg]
reverted c board zoomed


You can also see where they had cut the traces for pins 45 and 46, which would normally connect to that ground plane to the right.

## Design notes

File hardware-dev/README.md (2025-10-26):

# openkey-cps1-dev Hardware
This is a dev version of openkey-cps1 hardware that makes it possible to rapidly test firmware changes.  I'm mainly just including this in the repo so I don't use it.

**Top:**
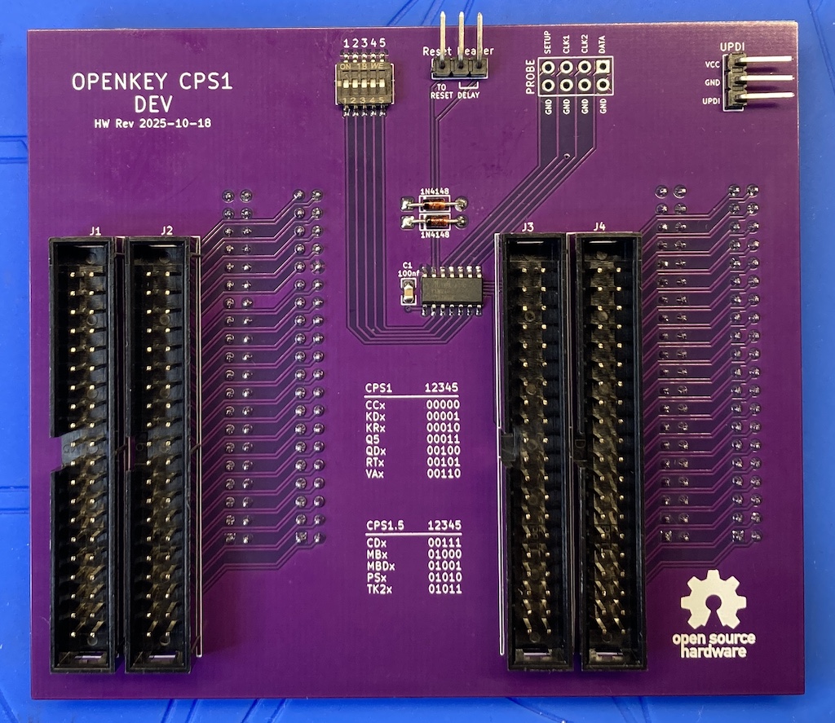
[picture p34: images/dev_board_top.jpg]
dev board top


**Bottom:**
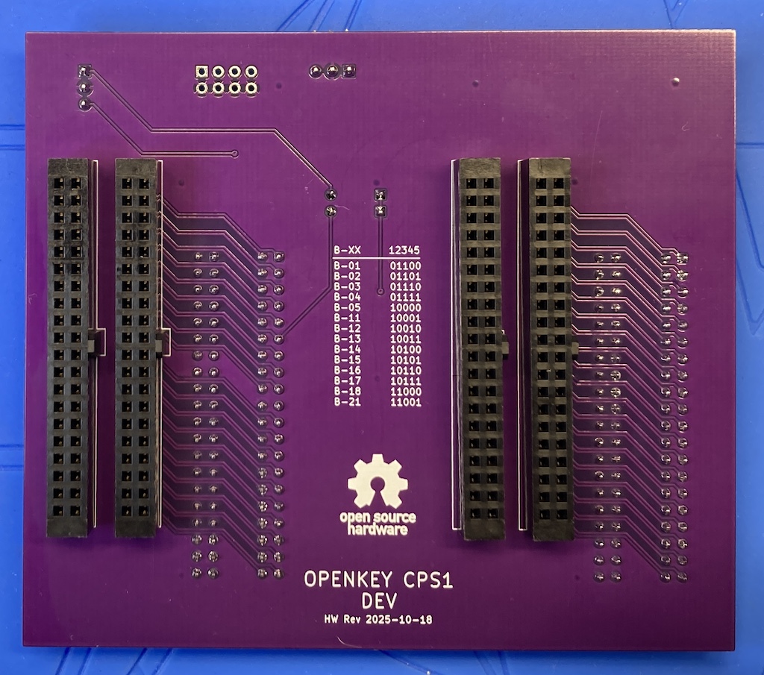
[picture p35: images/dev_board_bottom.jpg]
dev board bottom


As you can see its a bit taller then the non-dev version to allow being able to change the selected game and re-program the firmware while the board is plugged into a cps1 A-B-C stack.  The 2 diodes ensure that USB power can only goto the ATtiny and that cps1 board power doesn't goto the USB.

After programming the ATtiny you will want to disconnect it from USB and either power-on or powercycle the cps1 board.  This is to ensure power is fully removed from the ATtiny so it will boot up normally when cps1 power is applied.

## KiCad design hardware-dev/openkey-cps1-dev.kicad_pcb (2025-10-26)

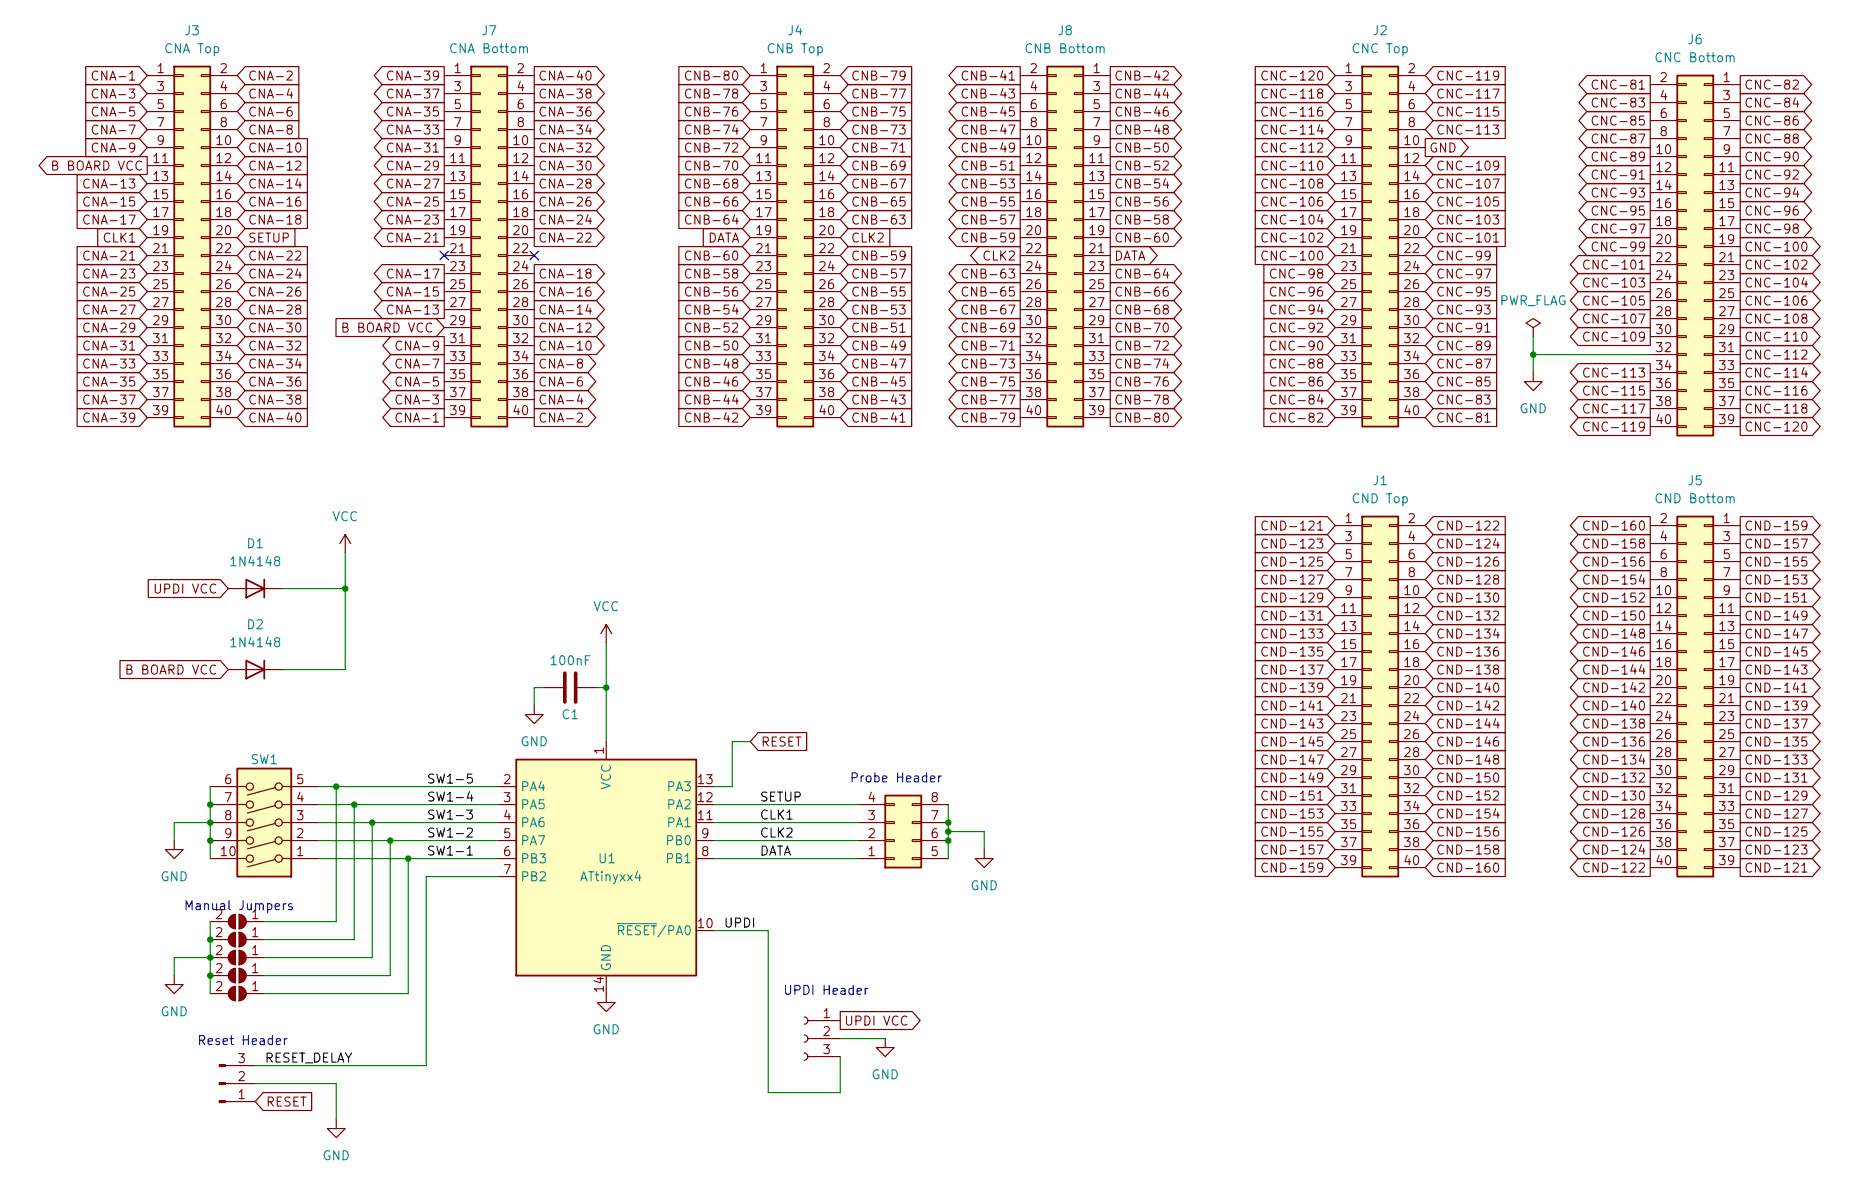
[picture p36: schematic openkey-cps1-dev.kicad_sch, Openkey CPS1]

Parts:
C1: 100nF; C_0805_2012Metric_Pad1.18x1.45mm_HandSolder
D1, D2: 1N4148; D_DO-35_SOD27_P7.62mm_Horizontal
J1: CND Top; IDC-Header_2x20_P2.54mm_Vertical_1.3mm
J2: CNC Top; IDC-Header_2x20_P2.54mm_Vertical_1.3mm
J3: CNA Top; IDC-Header_2x20_P2.54mm_Vertical_1.3mm
J4: CNB Top; IDC-Header_2x20_P2.54mm_Vertical_1.3mm
J5: CND Bottom; PinSocket_2x20_P2.54mm_Vertical_1.3mm
J6: CNC Bottom; PinSocket_2x20_P2.54mm_Vertical_1.3mm
J7: CNA Bottom; PinSocket_2x20_P2.54mm_Vertical_1.3mm
J8: CNB Bottom; PinSocket_2x20_P2.54mm_Vertical_1.3mm
J9: Conn_01x03_Female; PinHeader_1x03_P2.54mm_Vertical
J10: Conn_02x04_Top_Bottom; PinHeader_2x04_P2.54mm_Vertical
J12: Conn_01x03_Pin; PinHeader_1x03_P2.54mm_Vertical
JP1, JP2, JP3, JP4, JP5: SolderJumper_2_Open; SolderJumper-2_P1.3mm_Open_Pad1.0x0.6mm
SW1: SW_DIP_x05; SW_DIP_SPSTx05_Slide_Wurth_416131160805_W7.62mm_P1.27mm
U1: ATtinyxx4; SOIC-14_3.9x8.7mm_P1.27mm

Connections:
/RESET_DELAY: J12.3, U1.7 (PB2)
/SW1-1: JP5.1 (A), SW1.1, U1.6 (PB3)
/SW1-2: JP4.1 (A), SW1.2, U1.5 (PA7)
/SW1-3: JP3.1 (A), SW1.3, U1.4 (PA6)
/SW1-4: JP2.1 (A), SW1.4, U1.3 (PA5)
/SW1-5: JP1.1 (A), SW1.5, U1.2 (PA4)
/UPDI: J9.3, U1.10 (~RESET/PA0)
B BOARD VCC: D2.2 (A), J3.11, J7.29
CLK1: J3.19, J10.3, U1.11 (PA1)
CLK2: J4.20, J8.22, J10.2, U1.9 (PB0)
CNA-1: J3.1, J7.39
CNA-2: J3.2, J7.40
CNA-3: J3.3, J7.37
CNA-4: J3.4, J7.38
CNA-5: J3.5, J7.35
CNA-6: J3.6, J7.36
CNA-7: J3.7, J7.33
CNA-8: J3.8, J7.34
CNA-9: J3.9, J7.31
CNA-10: J3.10, J7.32
CNA-12: J3.12, J7.30
CNA-13: J3.13, J7.27
CNA-14: J3.14, J7.28
CNA-15: J3.15, J7.25
CNA-16: J3.16, J7.26
CNA-17: J3.17, J7.23
CNA-18: J3.18, J7.24
CNA-21: J3.21, J7.19
CNA-22: J3.22, J7.20
CNA-23: J3.23, J7.17
CNA-24: J3.24, J7.18
CNA-25: J3.25, J7.15
CNA-26: J3.26, J7.16
CNA-27: J3.27, J7.13
CNA-28: J3.28, J7.14
CNA-29: J3.29, J7.11
CNA-30: J3.30, J7.12
CNA-31: J3.31, J7.9
CNA-32: J3.32, J7.10
CNA-33: J3.33, J7.7
CNA-34: J3.34, J7.8
CNA-35: J3.35, J7.5
CNA-36: J3.36, J7.6
CNA-37: J3.37, J7.3
CNA-38: J3.38, J7.4
CNA-39: J3.39, J7.1
CNA-40: J3.40, J7.2
CNB-41: J4.40, J8.2
CNB-42: J4.39, J8.1
CNB-43: J4.38, J8.4
CNB-44: J4.37, J8.3
CNB-45: J4.36, J8.6
CNB-46: J4.35, J8.5
CNB-47: J4.34, J8.8
CNB-48: J4.33, J8.7
CNB-49: J4.32, J8.10
CNB-50: J4.31, J8.9
CNB-51: J4.30, J8.12
CNB-52: J4.29, J8.11
CNB-53: J4.28, J8.14
CNB-54: J4.27, J8.13
CNB-55: J4.26, J8.16
CNB-56: J4.25, J8.15
CNB-57: J4.24, J8.18
CNB-58: J4.23, J8.17
CNB-59: J4.22, J8.20
CNB-60: J4.21, J8.19
CNB-63: J4.18, J8.24
CNB-64: J4.17, J8.23
CNB-65: J4.16, J8.26
CNB-66: J4.15, J8.25
CNB-67: J4.14, J8.28
CNB-68: J4.13, J8.27
CNB-69: J4.12, J8.30
CNB-70: J4.11, J8.29
CNB-71: J4.10, J8.32
CNB-72: J4.9, J8.31
CNB-73: J4.8, J8.34
CNB-74: J4.7, J8.33
CNB-75: J4.6, J8.36
CNB-76: J4.5, J8.35
CNB-77: J4.4, J8.38
CNB-78: J4.3, J8.37
CNB-79: J4.2, J8.40
CNB-80: J4.1, J8.39
CNC-81: J2.40, J6.2
CNC-82: J2.39, J6.1
CNC-83: J2.38, J6.4
CNC-84: J2.37, J6.3
CNC-85: J2.36, J6.6
CNC-86: J2.35, J6.5
CNC-87: J2.34, J6.8
CNC-88: J2.33, J6.7
CNC-89: J2.32, J6.10
CNC-90: J2.31, J6.9
CNC-91: J2.30, J6.12
CNC-92: J2.29, J6.11
CNC-93: J2.28, J6.14
CNC-94: J2.27, J6.13
CNC-95: J2.26, J6.16
CNC-96: J2.25, J6.15
CNC-97: J2.24, J6.18
CNC-98: J2.23, J6.17
CNC-99: J2.22, J6.20
CNC-100: J2.21, J6.19
CNC-101: J2.20, J6.22
CNC-102: J2.19, J6.21
CNC-103: J2.18, J6.24
CNC-104: J2.17, J6.23
CNC-105: J2.16, J6.26
CNC-106: J2.15, J6.25
CNC-107: J2.14, J6.28
CNC-108: J2.13, J6.27
CNC-109: J2.12, J6.30
CNC-110: J2.11, J6.29
CNC-112: J2.9, J6.31
CNC-113: J2.8, J6.34
CNC-114: J2.7, J6.33
CNC-115: J2.6, J6.36
CNC-116: J2.5, J6.35
CNC-117: J2.4, J6.38
CNC-118: J2.3, J6.37
CNC-119: J2.2, J6.40
CNC-120: J2.1, J6.39
CND-121: J1.1, J5.39
CND-122: J1.2, J5.40
CND-123: J1.3, J5.37
CND-124: J1.4, J5.38
CND-125: J1.5, J5.35
CND-126: J1.6, J5.36
CND-127: J1.7, J5.33
CND-128: J1.8, J5.34
CND-129: J1.9, J5.31
CND-130: J1.10, J5.32
CND-131: J1.11, J5.29
CND-132: J1.12, J5.30
CND-133: J1.13, J5.27
CND-134: J1.14, J5.28
CND-135: J1.15, J5.25
CND-136: J1.16, J5.26
CND-137: J1.17, J5.23
CND-138: J1.18, J5.24
CND-139: J1.19, J5.21
CND-140: J1.20, J5.22
CND-141: J1.21, J5.19
CND-142: J1.22, J5.20
CND-143: J1.23, J5.17
CND-144: J1.24, J5.18
CND-145: J1.25, J5.15
CND-146: J1.26, J5.16
CND-147: J1.27, J5.13
CND-148: J1.28, J5.14
CND-149: J1.29, J5.11
CND-150: J1.30, J5.12
CND-151: J1.31, J5.9
CND-152: J1.32, J5.10
CND-153: J1.33, J5.7
CND-154: J1.34, J5.8
CND-155: J1.35, J5.5
CND-156: J1.36, J5.6
CND-157: J1.37, J5.3
CND-158: J1.38, J5.4
CND-159: J1.39, J5.1
CND-160: J1.40, J5.2
DATA: J4.19, J8.21, J10.1, U1.8 (PB1)
GND: C1.1, J2.10, J6.32, J9.2, J10.5, J10.6, J10.7, J10.8, J12.2, JP1.2 (B), JP2.2 (B), JP3.2 (B), JP4.2 (B), JP5.2 (B), SW1.6, SW1.7, SW1.8, SW1.9, SW1.10, U1.14 (GND)
RESET: J12.1, U1.13 (PA3)
SETUP: J3.20, J10.4, U1.12 (PA2)
UPDI VCC: D1.2 (A), J9.1
VCC: C1.2, D1.1 (K), D2.1 (K), U1.1 (VCC)

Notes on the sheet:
UPDI Header
Reset Header
Probe Header
Manual Jumpers

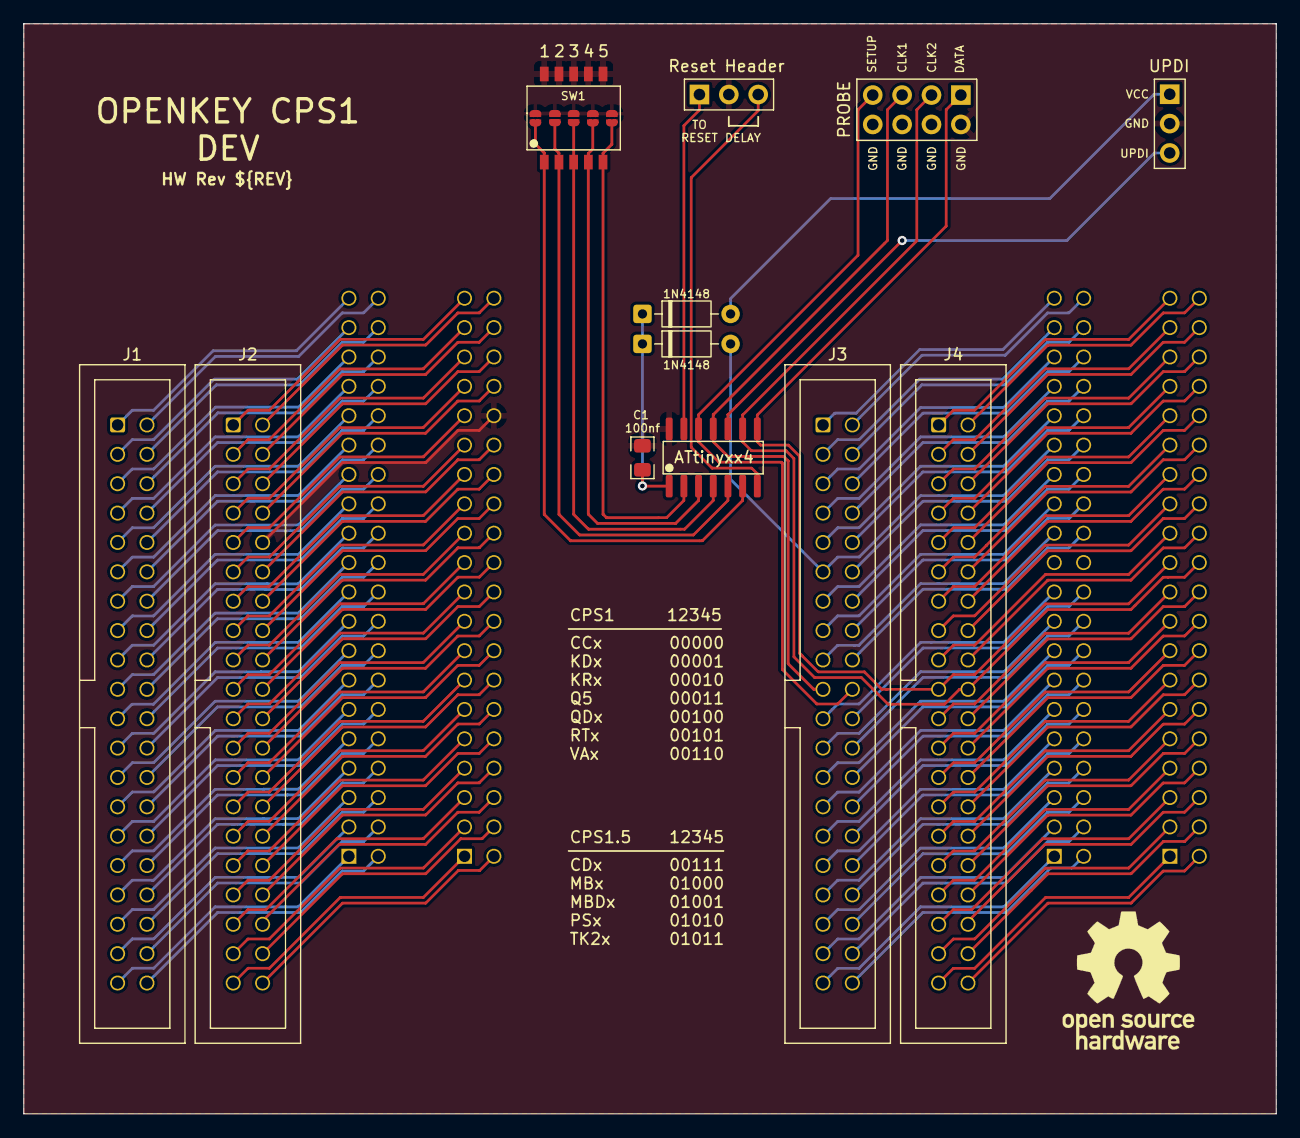
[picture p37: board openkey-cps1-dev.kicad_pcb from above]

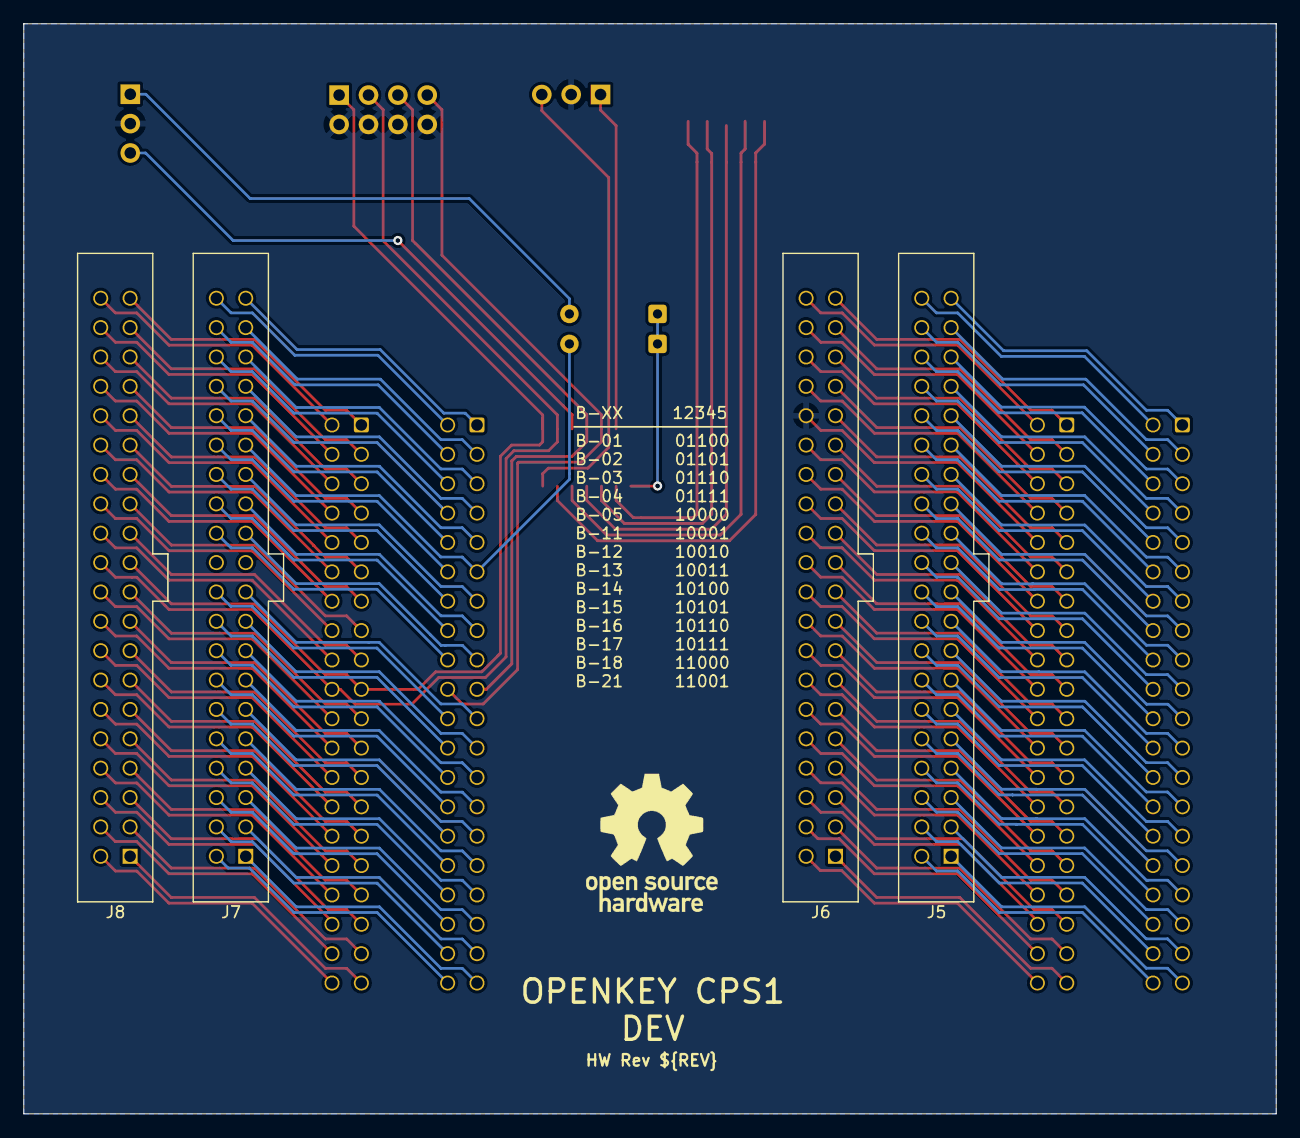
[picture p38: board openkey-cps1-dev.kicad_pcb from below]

Board: 2 copper layers, 108.3 x 94.3 mm, 21 parts (4 on the bottom side), 170 nets.

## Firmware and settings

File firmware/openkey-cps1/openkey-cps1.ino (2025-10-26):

#include <avr/sleep.h>
#include "cps1-configs.h"

// PIN 8 (PIN_PB1) <=> CNB PIN 62
#define SET_DATA      PORTB.OUTSET = PIN1_bm
#define CLR_DATA      PORTB.OUTCLR = PIN1_bm

// PIN 9 (PIN_PB0) <=> CNB PIN 61
#define SET_CLK2      PORTB.OUTSET = PIN0_bm
#define CLR_CLK2      PORTB.OUTCLR = PIN0_bm

// PIN 10 (PIN_PA0) used for UPDI (ATtiny programming)

// PIN 11 (PIN_PA1) <=> CNA PIN 19
#define SET_CLK1      PORTA.OUTSET = PIN1_bm
#define CLR_CLK1      PORTA.OUTCLR = PIN1_bm

// PIN 12 (PIN_PA2) <=> CNA PIN 20
#define SET_SETUP     PORTA.OUTSET = PIN2_bm
#define CLR_SETUP     PORTA.OUTCLR = PIN2_bm

// PIN 13 (PIN_PA3) <=> "A" board reset line (optional)
#define SET_RESET     PORTA.OUTSET = PIN3_bm
#define CLR_RESET     PORTA.OUTCLR = PIN3_bm

// reset delay jumper is jumped (hw rev 2025-10-18)
#define RESET_DELAY !(PORTB.IN & 0b0000100)

// doing bit shifting takes a variable amount
// of time depending on the how far the shift
// is.  Using the below lookup table to try
// and keep a consistent clock period when
// sending data.
uint8_t masks[8] = {
  0x01, 0x02, 0x04, 0x08,
  0x10, 0x20, 0x40, 0x80,
};

void setup() {
  // set the programming pins as outputs
  PORTA.DIR = PIN1_bm | PIN2_bm | PIN3_bm;
  PORTB.DIR = PIN0_bm | PIN1_bm;

  // setup initial output states
  // https://www.youtube.com/watch?v=IBZc__9sM28&t=1196s
  CLR_RESET;
  SET_SETUP;
  CLR_CLK1;
  CLR_CLK2;
  CLR_DATA;

  // enable pull-ups on dsw / reset delay pins
  PORTA.PIN4CTRL |= PORT_PULLUPEN_bm;  // PIN 2 (PIN_PA4) <=> DSW5
  PORTA.PIN5CTRL |= PORT_PULLUPEN_bm;  // PIN 3 (PIN_PA5) <=> DSW4
  PORTA.PIN6CTRL |= PORT_PULLUPEN_bm;  // PIN 4 (PIN_PA6) <=> DSW3
  PORTA.PIN7CTRL |= PORT_PULLUPEN_bm;  // PIN 5 (PIN_PA7) <=> DSW2
  PORTB.PIN3CTRL |= PORT_PULLUPEN_bm;  // PIN 6 (PIN_PB3) <=> DSW1
  PORTB.PIN2CTRL |= PORT_PULLUPEN_bm;  // PIN 7 (PIN_PB2) <=> RESET_DELAY Jumper

  // Testing Notes:
  // - using a delay down near 500us will cause some games to report an
  //   addresss or ram error on boot
  // - going below that, programming stops working
  delayMicroseconds(1000);

  if(RESET_DELAY) {
    delay(1000);
  }

  // stage #1: clocks on clock #1
  // https://www.youtube.com/watch?v=IBZc__9sM28&t=1232s
  for(int i = 0;i < 4;i++) {
    SET_CLK1;
    CLR_CLK1;
  }

  // using updated info for stage #2/3
  // https://gitlab.com/loic.petit/cps2-reverse/-/blob/master/DLs/DL-0921/doc/security-scheme.md
  // stage #2: unlock key
  send_bits(0x5, 3);

  // stage #3: clocks on clock #2
  for(int i = 0;i < 15;i++) {
    SET_CLK2;
    CLR_CLK2;
  }

  uint8_t config_num = read_dsw();
  if(config_num >= CONFIG_MAX) {
    config_num = CONFIG_MAX - 1;
  }

  for(int i = 0; i < CONFIG_SIZE; i++) {
    send_bits(chip_configs[config_num][i], 8);
  }

  CLR_CLK1;
  CLR_CLK2;
  CLR_DATA;
  CLR_SETUP;

  if(RESET_DELAY) {
    delay(1000);
  }

  // NOTE: We dont connect pins 19/20 between the C and B boards.  These
  // pins are needed for programming but are normally tied to ground on
  // the B board.  In testing it appears the cps-b-21 chip has an internal
  // pull down for both, so it should be safe to disable pin output and
  // power down the ATtiny.

  // set all pins to be inputs
  PORTA.DIR = 0;
  PORTB.DIR = 0;

  // power down
  set_sleep_mode(SLEEP_MODE_PWR_DOWN);
  sleep_enable();
  sleep_cpu();
}

void loop() {
  while(1) {}
}

void send_bits(uint16_t data, int8_t num_bits) {
  num_bits--;
  while(num_bits >= 0) {
    uint32_t bit = data & masks[num_bits];
    if(bit) {
      SET_DATA;
    } else {
      CLR_DATA;
    }
    SET_CLK2;
    CLR_CLK2;
    num_bits--;
  }
}

// DSW1 = PB3 = bit4
// DSW2 = PA7 = bit3
// DSW3 = PA6 = bit2
// DSW4 = PA5 = bit1
// DSW5 = PA4 = bit0
uint8_t read_dsw() {
  uint8_t dsw = 0;
 
  // negate the bits since we are using
  // pull-ups so "on"s will be low
  uint8_t porta = PORTA.IN ^ 0xff;
  uint8_t portb = PORTB.IN ^ 0xff;

  dsw = porta >> 4;
  dsw = dsw | ((portb & 0b0001000) << 1);
  return dsw;
}

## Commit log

2022-10-11 Add hardware
    [openkey-cps1.kicad_pcb, openkey-cps1.kicad_sch]
2022-10-11 Tweak a couple ground traces
    [openkey-cps1.kicad_pcb]
2022-10-12 Move firmware to a openkey-cps1 sub dir to keep arduino ide happy
2022-10-12 Add exported gerber directories to .gitignore
2022-10-27 Tweak vcc/gnd traces
    [openkey-cps1.kicad_pcb]
2022-11-17 Docs: programmer voltage switch
2025-10-26 Updated hardware/firmware that adds an optional reset header
    The optional reset header that can be used to hookup openkey-cps1
    to the A board's reset signal to allow openkey to control it. In
    general you shouldn't need this, but waited to make it an available
    option. More details are in the README.md
    The updated firmware is backwards compatible with the previous
    hardware revision.
    [openkey-cps1.kicad_pcb, openkey-cps1.kicad_sch]
2025-10-26 Add dev board
    This is the latest dev board that I use for testing firmware changes.
    [openkey-cps1-dev.kicad_pcb, openkey-cps1-dev.kicad_sch]
